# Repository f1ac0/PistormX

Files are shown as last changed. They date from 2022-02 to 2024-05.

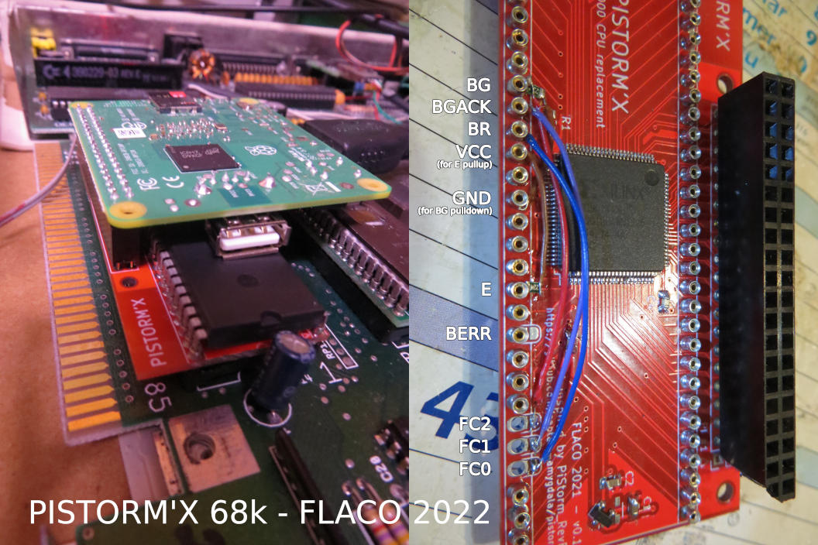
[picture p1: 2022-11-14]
Alpha/PiStormX-68k/PistormX68k.jpg

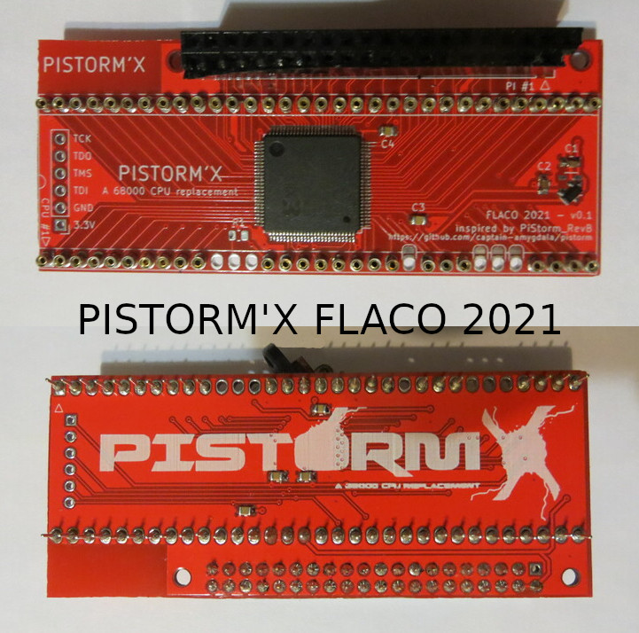
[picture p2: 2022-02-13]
Alpha/PistormX FLACO 2021.JPG

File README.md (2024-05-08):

# Pistorm'X
If you don't know about Pistorm, the MC68000 CPU replacement using a raspberry Pi, see here : https://github.com/captain-amygdala/pistorm

This PiStorm'X is a simplified CPU board, where all the logic is integrated inside a single CPLD with 5V compatible IOs.

The "Alpha" directory contains the PCB design and CPLD logic files for the first design of the Amiga 500 board and possible mods.

The "Beta" directory shares a second generation of boards for the Amiga 500, Amiga 600 and Amiga 1200. To enjoy both the speed of the PiStorm and the compatibility of the original hardware, they include the ability to disable the Pi and run the original 68k CPU, and the A500 and A600 ones also add 2MB of autoconfig Fast RAM.

Please read the README files there for more info.

# Experimental status
These boards are still experimental, not well tested, and might not work with all system revisions and Pi or 68k software nor provide the same performance or feature than the original. That it works for me does not mean that it will work for you. For this reason you are welcome to assemble your own and share test reports in the discord channel named "beta-testing-pistormx". And for this same reason this board or derivatives must not be sold to end users : do not sell it and do not buy it yet.

- I am an end user, where can I buy it? Buy one of the original PiStorm CPU boards.
- I am a builder, can I sell it? For now, please test it and report your test results.
- I am a maker, can I build derivatives? For now, please test it and report your test results.

# Acknowledgements
The board and its firmware are inspired by the original Pistorm : https://github.com/captain-amygdala/pistorm.
I would like to thank Claude Schwarz for designing and open sourcing the Pistorm and for letting other projects like this one use the name and get inspired by the source code.
Thank you also to EDU_ARANA for letting me use his Pistorm logo with some modifications on the PCB silkscreen.
It is not supported by the PiStorm developers, please don't bother them with issues you might have with it.

# Disclaimer
This is a hobbyist project, it comes with no warranty and no support. Also remember that the Amiga machines are about 30 years old and may fail because of such hardware expansions. Use with caution it could burn your Pi, your Amiga, your house.

I publish my work under the CC-BY-NC-SA license. You may build a board for you or your friend but will not sell or buy it commercially because it is experimental. You must keep the original author's name, source repository (https://github.com/f1ac0/PistormX) and licensing conditions even if you modify the product.

If you find it useful and want to reward my hard work : I am always looking for Amiga/Amstrad CPC and such retro hardware to repair and hack, or software licenses for these. Other than that, give to charities and reduce your carbon footprint.

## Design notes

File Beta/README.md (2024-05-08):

# PiStorm'X Work in progress

NOT ALL DESIGNS IN THIS DIRECTORY ARE TESTED.

If you don't know about PiStorm, the MC68000 CPU replacement using a raspberry Pi, see here : https://github.com/captain-amygdala/pistorm. This PiStorm'X is a simplified CPU board, where all the logic is integrated inside a single CPLD.

# Experimental status
These boards are either experimental, not finished, not yet tested, and might not work for you, have bugs with some system revisions and Pi or 68k software, or have less performance or feature than the original. For this reason you will find here source files only, not fabrication files or ready to use binaries. If you have enough development skills to use them and know what you are doing, you may assemble your own and share test reports in the discord channel named "beta-testing-pistormx". And for this same reason these boards or derivatives must not be sold to end users.

I publish my work under the CC-BY-NC-SA license. You may build a board for you but will not sell or buy it commercially because it is experimental. You must keep the original author's name, source repository (https://github.com/f1ac0/PistormX) and licensing conditions even if you modify the product.

If you find it useful and want to reward my hard work : I am always looking for Amiga/Amstrad CPC/C64 and such retro hardware to repair and hack, or software licenses for these. Other than that, please give to charities and reduce your carbon footprint.

# Acknowledgements
The board and its firmware are inspired by the original PiStorm : https://github.com/captain-amygdala/pistorm.
I would like to thank Claude Schwarz for designing and open sourcing the PiStorm and for letting other projects like this one use the name and get inspired by the source code.
Thank you also to EDU_ARANA for letting me use his PiStorm logo with some modifications on the PCB silkscreen.
It is not supported by the PiStorm developers, please don't bother them with issues you might have with it.

# PiStorm'X 500
The original PiStorm'X project for the Amiga 500 was shared in February 2022. In November 2022, I published the PiStorm'X-68k, a modification to the original project that allow keeping and using the original 68000 by deactivating the PiStorm when needed using a long reset.

This PiStorm'X 500 is an updated board for the Amiga 500 :
- including the PiStorm'X-68k modifications,
- moving the Pi away from the 68000, over the A500 ROM, in order to improve thermal repartition,
- adding 2MB of Fast RAM, which is useful especially during 68000 operation when the Pi is disabled : there was enough room on the two sided board and I believe it is a nice addition to the stock Amiga 500.

/!\ This 1.0 revision board need a patch wire between pin 15 of the 68k header to the pad marked OVR /!\ Do not connect anything else to this pad and check that the BGACK solder jumper is not shorted to the BGACK pin. /!\

The development of this board has been painful. I killed the 7805 Super Fat Agnus of my Rev8a in the development process, because of a dodgy home designed and printed ZIF64 socket that doesn't lock correctly, and an idiot operator that touched the pins without ESD protection. I am looking for an affordable replacement. Then I fought a timing problem caused by the slow transition on the 7MHz clock, because I thought it was a good idea to route it to a global clock pin of the CPLD. It was not - see https://support.xilinx.com/s/article/3226, on the Rev6 with Agnus 8372 318069-02 they are about 25ns, compared to 10ns on my A600 Rev1.5 with Agnus 8375 318069-10 - and this is the reason for the patch wire.

This board is actually working on my A500 Rev6.

# PiStorm'X 600
The PiStorm'X 600 brings the same features as the PiStorm'X 500 to the Amiga 600 : maintain reset during 6 seconds or more to use the 68000, and benefit of 2MB of Fast RAM.

This board is actually working on my A600.

# PiStorm'X 1K2
I have heard about the PiStorm32 for the Amiga 1200 and I wanted to make my own in the Pistorm'X way.

This is not yet finished and untested.

- There are two board layouts : the first board steals the component placement form the PiStorm32-lite ; the second "alt" one offers a more "traditional" design to access the Pi in the trapdoor. Both boards share the same logic but have different CPLD pinout and so will require different bitstreams. With the latter if you don't mind leaving the trapdoor open you may install a standard pin header for the Pi GPIO, leaving the A1200 edge connector as the only special part.
- Since it needs to cope with 32 bits operation with misaligned addresses and dynamic bus sizing, it requires a larger XC95288 CPLD, both in pin count and macrocells.
- This added logic must still be full of bugs and may never work.
- I reused the Pi pinouts from the Pistorm32-lite and since it does not have room for the jtag anymore, the device needs to be programmed externally.
- Even with the same Pi pinouts, it will need updated emulators that does not try to program a FPGA at power up : I hope this will be possible to deactivate it in future upstream releases.
- Like the original PiStorm'X that is not limited by external buffers, it might also be possible to use a faster protocol to speed up chip access a little bit. Or offload some complexity to the emulator to fit inside an even smaller/cheaper CPLD.

For sure this will need some more effort to first make it work !

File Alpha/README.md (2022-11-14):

# Pistorm'X
If you don't know about Pistorm, the MC68000 CPU replacement using a raspberry Pi, see here : https://github.com/captain-amygdala/pistorm

This Pistorm'X is a simplified CPU board, where all the logic is integrated inside a single XC94144XL-10TQ100 CPLD with 5V compatible IOs.

It has major differences in the logic implementation to accommodate the slower CPLD and may behave differently than the original Pistorm CPU board. A challenge has been to get rid of the 200MHz clock since the fastest Xilinx part in this series, the 5ns one, is rated for 178MHz max and is overpriced because of the chip shortage. Not using the PI_CLK makes the firmware really different from the original : a standard 10ns XC95144 can now deal with both the M68000 bus cycle synchronously to the 7MHz clock, and the asynchronous communication with the Pi that is just within the 10ns limit. 

The Pistorm'X logic is also provided for the original Pistorm CPU board. See the CPLD/Pistorm subdirectory to try it on your board.

Why you may consider building a Pistorm'X :
- This is even cheaper than the original board thanks to its single chip and 2-layer PCB.
- It is easier to assemble manually : there is only one QFP package, the board is less crowded, with 0805 caps, and the friendly 2-layer PCB with thermal relief makes it less vulnerable to cold joints.
- Maybe this will prove to be a suitable CPU board replacement. Your test contribution can help that.
- It runs with the same Pi software. Except CPLD programming : do not burn Altera bitstream on Xilinx device or vice versa !
- Because everything is reprogrammable in the CPLD, it may do things not possible on the original hardware :
  - Buffering write operations,
  - Installing it at the same time as the 68000 CPU : check the PistormX-68k folder for more info.

Why you should prefer the original CPU board :
- This Pistorm'X is alpha status. So far it is not guaranteed that it will work in your system or support all the features of the original.
- It is not an official board.
- It will probably not be compatible with future improvements or there will be delays to implement them.
- The actual CPLD pinout was chosen only to ease PCB routing and use a cheap 2-layers PCB. Future versions for different targets (A600, A2000...) will probably do the same and require a different CPLD pinout for each board, which means dedicated firmware files.
- The v0.1 board was routed with the actual Pistorm firmware in mind, so actually the 7MHz clock does not take advantage of a Global Clock pin of the CPLD : pinout may also change in next releases of this board.

# Experimental status
This board is experimental, not yet well tested, and might not work with all system revisions and Pi or 68k software or provide the same performance or feature than the original. That it works for me does not mean that it will work for you. For this reason you are welcome to assemble your own and share test reports in the discord channel named "beta-testing-pistormx". And for this same reason this board or derivatives must not be sold to end users : do not sell it and do not buy it yet.

- I am an end user, where can I buy it? Buy an original Pistorm CPU board.
- I am a builder, can I sell it? For now, please test it and report your test results.
- I am a maker, can I build derivatives? For now, please test it and report your test results.

Available firmwares:
- 8 states cycle : follow the complete 8 states 68k bus cycle described in MC68000 user manual.
- 6 states cycle : use a 6 states bus cycle by skipping s5 and s6 states. Similar to the original Pistorm firmware that skip s7 and s0 to increase chip access speed according to SysInfo.
- 6 states cycle write buffer : use CPLD registers as double buffer to releases the Pi bus earlier during write operations ; SysInfo show a tiny increase in CPU performance but not in chip ram access speed.
- 4 states cycle : use a 6 states bus cycle by skipping s0, s1, s5 and s6 states.
- 4 states cycle write buffer : use a 4 states bus cycle and a write buffer ; no real speed increase according to SysInfo, maybe useful in other apps.

Tested so far :
- inside my own Amiga 500 rev8a,
- buptest,
- Musashi based emulator with basic configuration and KS1.3, 3.1 and DiagROM, few demos and games from floppy,
- EMU68 with HDD install of KS3.1, RTG and WHDLoad games, demos.

Os runs stable for hours installing files from floppies or from SDbox. All the many glitches and errors that I found in games and demos (music not in sync, freeze) so far are similar when using the Pistorm'X or the Pistorm.

# Acknowledgements
The board and its firmware are inspired by the original Pistorm : https://github.com/captain-amygdala/pistorm.
I would like to thank Claude Schwarz for designing and open sourcing the Pistorm and for letting other projects like this one use the name and get inspired by the source code.
Thank you also to EDU_ARANA for letting me use his Pistorm logo with some modifications on the PCB silkscreen.
It is not supported by the Pistorm developers, please don't bother them with issues you might have with it.

# Disclaimer
This is a hobbyist project, it comes with no warranty and no support. Also remember that the Amiga machines are about 30 years old and may fail because of such hardware expansions. Use with caution it could burn your Pi, your Amiga, your house.

I publish my work under the CC-BY-NC-SA license. You may build a board for you or your friend but will not sell or buy it commercially because it is experimental. You must keep the original author's name, source repository (https://github.com/f1ac0/PistormX) and licensing conditions even if you modify the product.

If you find it useful and want to reward my hard work : I am always looking for Amiga/Amstrad CPC and such retro hardware to repair and hack, or software licenses for these. Other than that, give to charities and reduce your carbon footprint. 

# BOM
- 1x XC95144XL-10TQ100 CPLD
- 1x 3.3v LDO, either SPX3819M5-L-3-3 or XC6206P332MR or equivalent
- 2x 1uF (or more) 0805 capacitors in C1 and C2
- 6x 100nF 0805 capacitors
- (1x 10k 0805 resistor in R1, not required in my case)
- 64x rounded socket pins. I use pins taken from a socket header. You can omit pins 11,12,13,22,26,27 and 28.
- 1x 2x20 2.54mm female pin header.

# Making it
Components are SMD, and have thin pin pitch. You need to know what you are doing.

Check for shorts at least between 5V, 3.3V, and GND traces before applying power !

CPLD code is generated and built using Xilinx ISE 14.7 IDE. Use the following process properties : opt_mode=Speed; opt_level=High; optimize=Speed; slew=Slow; terminate=Keeper.

The "JTAG" programming port does not need to be soldered since the CPLD can be programmed from the Pi itself, or if you use a separate programmer you can just maintain the connector in place during the few seconds required for programming.

To program it outside of the Amiga using the JTAG port, I use xsvfduino : https://github.com/wschutzer/xsvfduino. When it is already plugged to the motherboard, you must disconnect the 3.3v wire and turn on your system to power the board, otherwise your programmer will try to power the whole system, it will not work, and it might burn.

# Installation on the motherboard
Do NOT install the original CPU on top of the board inside the socket pins : leave it empty. I decided to use these because I previously used them for my IDE-RAM-A500 expansion, they fit well, and are cheaper, shorter and probably stronger than male rounded pins.

Some features use the Pi GPIOs that are connected to the JTAG programming port. You can connect your wires there if you want. For example EMU68 logging should be on TCK (untested).

# Programming the CPLD from the Pi
Instead of using the JTAG port you can program the CPLD from the Pi when it is already installed and powered by the Amiga motherboard.

Long story : see https://linuxjedi.co.uk/2021/11/25/revisiting-xilinx-jtag-programming-from-a-raspberry-pi/amp/. Thank you LinuxJedi for this HowTo.

```
sudo apt install build-essential libusb-dev libftdi-dev libgpiod-dev git cmake
git clone https://github.com/matrix-io/xc3sprog
```
Before building, edit xc3sprog/sysfscreator.cpp and change :
```
IOSysFsGPIO(24, 26, 27, 25)
```
Build:
```
mkdir xc3sprog/build
cd xc3sprog/build
cmake .. -DUSE_WIRINGPI=OFF
make
```
Flash:
```
sudo xc3sprog -c sysfsgpio_creator -v -p 0 pistormx.jed
```

# Using it
See the official Pistorm documentation.

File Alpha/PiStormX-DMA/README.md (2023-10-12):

# Pistorm'X with bus arbitration for DMA enabled peripherals
While discussing with a fellow PiStorm user on the AmigaFrance Forum, I discovered that peripherals that use Direct Memory Access (DMA) on the Amiga 2000 do not work with the actual PiStorm CPU boards. Having never used a "big box" Amiga myself I did not know about this fact.

Looking at the schematic of the A2000, I believe the CPU board need to support bus arbitration signals (BR, BG, BGACK) in order to float the address and data buses when other devices need them. On the PiStorm'X-68K logic, I used these signals, but as a bus master device in a reverse way to shut the real 68000 when the PiStorm emulator is active. However this means that the signals are available to the CPLD and the logic can be changed to behave like a CPU supporting DMA requests.

The files in this directory are an attempt to add the support of bus arbitration signals to the first PiStorm'X CPU board (not the ones in the Beta directory).
- They are not tested since I don't own an Amiga 2000. If you want to test it yourself on your system, feel free. If you have a spare/unused/broken one and want to make a donation to help the project, I'd be very happy.
- BR, BG, BGACK need to be connected as explained below on the first PiStorm'X board : if not, BR will be floating which will produce unexpected results
- The real 68000 need to be removed from the system/NOT installed on the PiStorm'X. Since the bus arbitrations are used in a normal "CPU way" this leaves now way to shut it down like the PiStorm'X 68K does. Il you install both the real 68K an the PiStorm they will use the bus at the same time, this will not work, and will probably break them.

When this is proven to work, I believe it will be great to build an A2000 CPU board with support to both the DMA devices and the real 68000.

# Experimental status
Pistorm'X is experimental, not yet well tested, and might not work with all system revisions and Pi or 68k software or provide the same performance or feature than the original. That it works for me does not mean that it will work for you. For this reason you are welcome to assemble your own and share test reports in the Discord channel named "beta-testing-pistormx".

Pistorm'X-DMA is even more experimental and untested.

# Making it
The first Pistorm'X board require a few modifications and a new firmware
- Connect the pin in _BG = CPU pin 11 to the solder jumper pad next to FC2 = CPU pin 26
- Connect the pin in _BGACK = CPU pin 12 to the solder jumper pad next to FC1 = CPU pin 27
- Connect the pin in _BR = CPU pin 13 to the solder jumper pad next to FC0 = CPU pin 28
- Pins in FC0 = CPU pin 28, FC1 = CPU pin 27 and FC2 = CPU pin 26 are still not required. If you install them you need to be careful NOT to connect them to the nearby jumper pad.

A board already modded for the PiStorm'X-68K will not need any modification.

Build the firmware using the same settings as the Pistorm'X and flash it on the CPLD using xsvfduino, xc3sprog or your preferred method.

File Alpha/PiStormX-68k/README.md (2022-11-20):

# Pistorm'X together with a 68000 chip ?!
Installing a fast Amiga accelerator breaks compatibility with original games and demos. Users of these devices such as the Pistorm are forced to rely on WHDload, or to have another Amiga on their desk to have access to these many legacy softwares.

The Pistorm'X-68k is now the solution to boot either the Pistorm or the original 68000 CPU inside one single machine.

Power on and boot using the Pistorm. Maintain a long reset and the Amiga will now boot using the 68k.

The Pistorm'X was created in 2021 as a replacement CPU board for the Pistorm, using less components, a cheaper PCB, easier to assemble, and freeing a GPIO pin on the Pi. Since they were more robust and lower profile, I used the same female pins as my A500-IDE-RAM board to attach the board to the host motherboard. I also broke out a few unused signals on solder jumpers. Along with a new firmware, these make it possible to modify existing Pistorm'X boards to host the DIP 68000/68010 !

To make room for the huge clock counter required to time the long reset, the double write buffering has been removed from this firmware : it is similar to the "4 states cycle" version of the PistormX firmwares.

# Experimental status
Pistorm'X is experimental, not yet well tested, and might not work with all system revisions and Pi or 68k software or provide the same performance or feature than the original. That it works for me does not mean that it will work for you. For this reason you are welcome to assemble your own and share test reports in the Discord channel named "beta-testing-pistormx".

Pistorm'X-68k is even more experimental.

# Making it
The Pistorm'X board require a few modifications and a new firmware ! Do not plug a 68k unless these mods have been completed !
- Install the Pi socket as high as possible : it is possible to gain 1 to 2 millimetres this way, otherwise the USB port touching the top of the 68000 will prevent to seat the Pi correctly and may lead to bad contacts problems.
- Install a pulldown on _BG = CPU pin 11 through a ~20K resistor to GND = CPU pin 16 or 53
- Install a pullup on E = CPU pin 20 through a 100~200K resistor to VCC = CPU pin 14
- Connect the pin in _BG = CPU pin 11 to the solder jumper pad next to FC2 = CPU pin 26
- Connect the pin in _BGACK = CPU pin 12 to the solder jumper pad next to FC1 = CPU pin 27
- Connect the pin in _BR = CPU pin 13 to the solder jumper pad next to FC0 = CPU pin 28
- Install a pin in the BERR hole = CPU pin 22 : it is not used by the Pistorm however the 68k require the pullup provided by the motherboard.
- Pins in FC0 = CPU pin 28, FC1 = CPU pin 27 and FC2 = CPU pin 26 are still not required. If you install them you need to be careful NOT to connect them to the nearby jumper pad.

Build the firmware using the same settings as the Pistorm'X and flash it on the CPLD using xsvfduino, xc3sprog or your preferred method. However I recommend to install a 68K only after it has been updated and modified successfully.

# Using it
You should consider active cooling when using the original board with the Pi placed just over the 68000, especially if you use the system for long periods. New boards layouts may solve this by placing the Pi over the A500 ROM (and with the ARM CPU on the top ?).

When no Pistorm emulator is active, the system boots using the 68000.

As soon as the Pistorm emulator starts, the system will reboot using the Pistorm. Maintain the reset during at least 6 seconds to disale Pistorm and use the 68000. Maintain a long reset again to go back to the Pistorm.

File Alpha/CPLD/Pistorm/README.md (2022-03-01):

# Pistorm'X firmwares for the original Pistorm CPU board
If you don't know about Pistorm, the MC68000 CPU replacement using a raspberry Pi, see here : https://github.com/captain-amygdala/pistorm

The Pistorm'X is a simplified CPU board, where all the logic is integrated inside a single XC94144XL-10TQ100 CPLD with 5V compatible IOs. See here : https://github.com/f1ac0/PistormX

It has major differences in the logic implementation to accommodate a slower CPLD, especially getting rid of the 200MHz clock, freeing one GPIO for future use.

Here you can find adapted Pistorm'X firmwares to be used on the original Pistorm CPU board with external buffer chips :
- basic : mostly similar to the features of original Pistorm firmware.
- skip s5s6 : skip s5 and s6 states when not in peripheral bus cycle.

Provided .svf files are built for the EPM240 CPLD.
Do not burn Altera bitstream on Xilinx device or vice versa ! Use with caution it could burn your Pi, your Amiga, your house.

# Experimental status
Actually even if they succeed the buptest and boot both Musashi and EMU68, they are unstable on my board. For example in amigaTestKit, testing the RTC clock does crash : maybe it has something to do with peripheral cycles.

Pistorm'X is experimental, not yet well tested, and might not work with all system revisions and Pi or 68k software or provide the same performance or feature than the original. That it works for me does not mean that it will work for you. For this reason you are welcome to assemble your own and share test reports in the Discord channel named "beta-testing-pistormx".

# Making it
Clone the Pistorm repo and replace the verilog file in the rtl subdirectory.

Build from the command line, replacing the path and version of your Quartus installation :
```
~/Quartus/17.0/quartus/bin/quartus_sh --flow compile pistorm
~/Quartus/17.0/quartus/bin/quartus_cpf -c -q 100KHz -g 3.3 -n p output_files/pistorm.pof pistorm.svf
```
If you choose to build it from the interface, make sure to set the correct 100KHz frequency in the programmer/svf options.

# Programming the CPLD from the Pi
Replace EPM240_bitstream.svf with the new .svf file, then run flash.sh as you usually do.

# Using it
See the official Pistorm documentation.

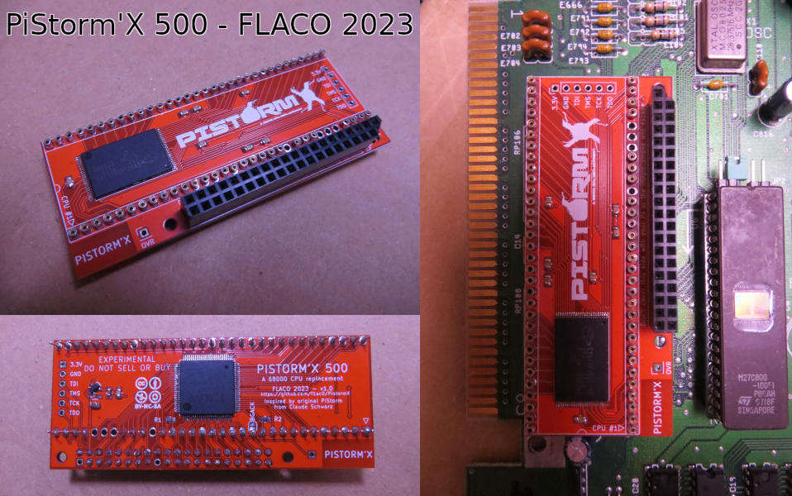
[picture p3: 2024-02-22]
Beta/PistormX 500 DIP/PiStormX500.jpg

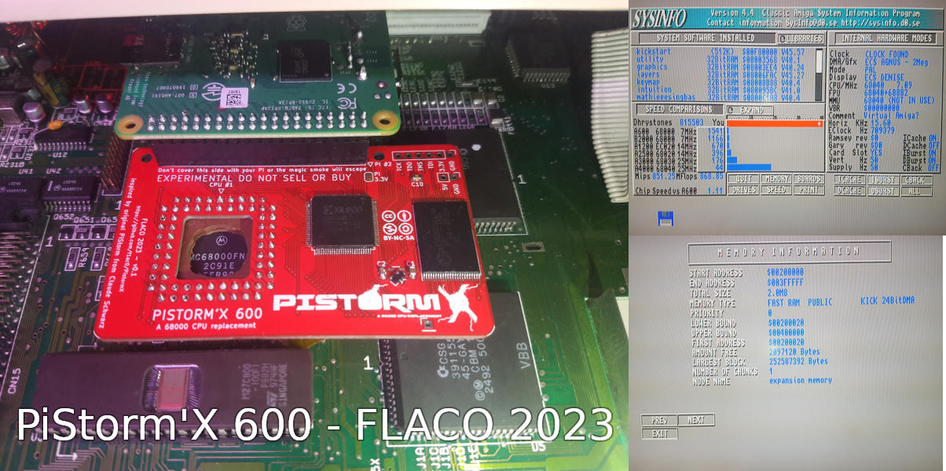
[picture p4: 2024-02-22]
Beta/PistormX 600/PiStormX600.jpg

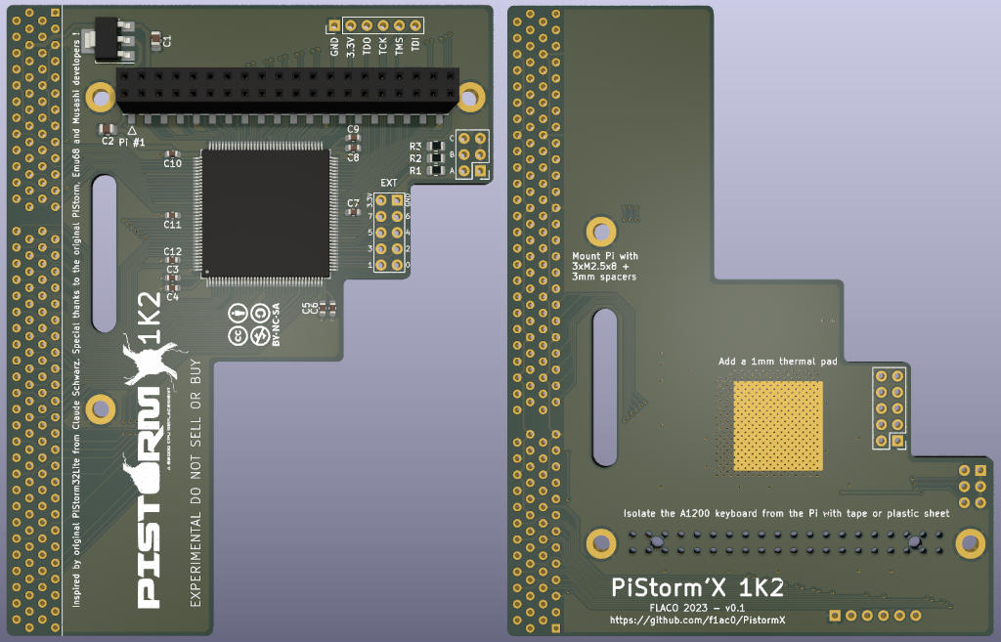
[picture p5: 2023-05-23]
Beta/PistormX 1K2/PiStormX1K2.jpg

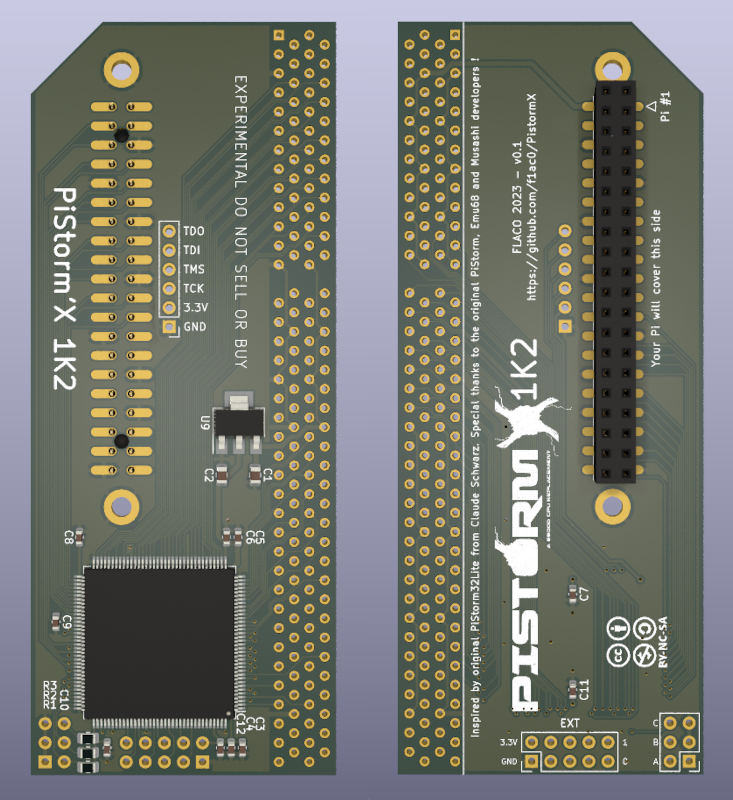
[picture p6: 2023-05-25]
Beta/PistormX 1K2 alt/PiStormX1K2 alt.jpg

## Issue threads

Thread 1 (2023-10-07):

PistormxDMA Amiga 2000 eatx troubles.

Trakman500, 2023-10-07:
Hello! I’ll describe it in order: pistormx of the first revisions (without expansion cards in Zorro) - problems with the mouse cursor which trembles convulsively on the screen and is practically uncontrollable. Changing the firmware and modifying the pistormx itself to support dma solves the problem with the mouse. everything works well. When you insert a sound card into a Zorro slot (any), instead of sound from the card, a high-frequency loud noise is emitted and music plays very quietly... prlcheck (prelude utility) displays an error that changes when the utility itself is launched again.
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

f1ac0, 2023-10-08:
Hi.
I am happy to have feedback from a PiStormX user.
Thank you for sharing your experience with the A2000, which seems to prove that the PiStormX-DMA logic is working. On my side, I couldn't find an A2000 at a decent price to test it, and to create a CPU board supporting both the 68k and the bus arbitration/DMA at the same time.

About the Prelude, and PrlCheck : according to your screenshot, it does something with address 0xE90000 which is "Secondary  [auto-config space]  (usually 64K I/O boards)" according to the Amiga memory map. I believe you are using Emu68 ; according to the last source files it does not seem to have a special behavior when accessing this address range (https://github.com/michalsc/Emu68/blob/0eaf3ab2c0641bb168b6b0c8c862182f3b8353cf/src/aarch64/vectors.c#L401) and I believe it also does not use cache (https://github.com/michalsc/Emu68/blob/0eaf3ab2c0641bb168b6b0c8c862182f3b8353cf/src/cache.c#L212). If you are using this same version, I do not see an obvious problem here.

On the hardware side, looking at the A2000 schematic, I believe that it is not a problem with logic voltage levels since address and data buses are buffered by U600-U604. Otherwise some CMOS chip on the expansion board might have not registered correctly the 3.3V outputs form the CPLD on the PiStorm'X board. (or it uses E, VPA and VMA that are not buffered).

The last thing I can think of is timing problem, especially if the offset of the error changes when you run  prlcheck several times. For this it could be useful to confirm the address it uses and probe the bus to see what is happening.

Trakman500, 2023-10-09:
After much torment with the a2k and the card, I decided to plug everything back into the a500... I connected the pi storm there and heard the same grinding and whistling noise as on the a2000! Well, I immediately thought maybe something had happened to my card... I returned the firmware and turned everything on again on the a500, the sound became normal... I put the pi storm with sound back in a2k, there is no sound at all, the card is checked with the same errors... I flashed back the pi storm with DMA support... the same thing, but there was a grinding and whistling noise... checking the prelude with the utility again produced chaotic errors and the guru machine when accessing the card... recorded some guru errors - 8000 0004 - 08184800, 08183260, 081е43f0, 08003020 etc
 The utility's check of the card sometimes goes through completely, but the test sound it makes is still the same bad noise...

f1ac0, 2023-10-09:
I recommend installing only boards+firmware that are aware of bus arbitration/DMA/bus master inside systems or with expansion boards that use it. Otherwise both the CPU board and expansion boards will talk at the same time on the buses, making unpredictable behavior, and maybe breaking something.

On the A500 where BR and BGACK are pulled up and not connected anywhere else, the PiStormXDMA logic will behave the same as the "pistormx - 4 states cycle write buffer" one. If this is the one you "returned to", I honestly don't understand what happened on the A500 at least. Do you unplug the board each time you flash it, and maybe there could be a bad contact somewhere/sometimes (even though all signals on the 68k socket are digital and a bad contact will prevent it to work at all - but maybe on the interrupt lines, audio channels from paula being interrupt 4 ?)

Before your last message, I was wondering if the JIT settings in emucontrol could change something with the prelude card like it does for some games?

Trakman500, 2023-10-10:
Today I’ll try to play around with the emu68 control in symbiosis with the Prelude checking utility.

Trakman500, 2023-10-11:
hi! In principle, I did not achieve any big changes. pistorm equipped with jumpers so that they can be removed or installed at any time.
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
I noticed that with them (jumpers) and without them on the a2000 everything is determined and works the same... I achieved the following results with it, but they are also not constant...
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

Trakman500, 2023-10-12:
I found on one of the forums that the prelude works on a2k with the original pi storm -

Ich hab ja mit Spannung auf den Treiber gewartet. Denn die Prelude (bzw. das Replikat) war in meinem A2000 mit Emu68 / Pistorm und dem Emu68 RTG Treiber mit den alten Treibern als Soundkarte per AHI oder Prelude direkt kaum sinnvoll nutzbar. Es kam ständig zu Abbrüchen.

Und in der Tat funktioniert genau das jetzt erfreulich gut. Wo es vorher zu Abbrüchen kam, stottert es jetzt leicht und insgesamt ist das Playback insgesamt viel stabiler. Gestern abend hat das System mit AmigaAMP 3.33 und MP3 Playback via AHI fast drei Stunden lang problemlos durchgehalten. Auch Hippoplayer dudelt jetzt schon eine Weile problemlos vor sich her.

Einzig Play16 per direktem Prelude Output spielt erst problemlos und hängt dann nach ein, zwei Minuten einfach ohne Möglichkeit zum Abbruch. Beim Playblack via AHI passiert das nicht. Wobei das natürlich auch Zufall sein kann, mein Setup ist ja in dieser Form eher experimentell.

A2000 Rev.6, Pistorm 2k / Emu68, AmigaOS 3.2.1, Freeway Pro, X-Surf 100, AT-Bus Clone, Prelude + MPEGit Replikat

https://www.a1k.org/forum/index.php?threads/85465/page-8

Why does pi storm x behave like this? Today I'll try all the firmwares.

Trakman500, 2023-10-12:
I tried it a little later... same result

Trakman500, 2023-10-12:
I conducted the same experiment again with the DMA firmware and the removed jumpers that I installed on the pistormx - on the a500... it loads normally, the prelude is detected perfectly, but when I launched the digibooster I noticed how slowly the windows were drawn on the screen... choosing the prelude as the sound device and After loading the module, I heard the same creaking and noise... I changed the firmware to 6 state, everything worked fine on the a500...

f1ac0, 2023-10-12:
>I found on one of the forums that the prelude works on a2k with the original pi storm
What I see in original PiStorm logic is that bus arbitration signals M68K_BR_n, M68K_BGACK_n are not connected anywhere and M68K_BR_n is tied up.
If the prelude works with that, then it does not use DMA.

I read here https://www.amigaimpact.org/forums/topic/tableau-perf-winuae/page/6/#post-375851 that it is recommended to use a "long hold" firmware to use the original PiStorm inside an A2000. I can see some binary files by this name here https://github.com/LemaruX/PiStorm-Firmware/tree/main however I cant find a source for it.

>with the DMA firmware and the removed jumpers
Without the jumper wires I can see on your photo, then the BR input of the DMA firmware is floating and receiving noise from ambient, so the CPLD logic might be requesting the bus and releasing it randomly.
This can explain your following sentence since according to pure randomness the bus throughput could be halved :
>when I launched the digibooster I noticed how slowly the windows were drawn on the screen

You should leave your jumper wires always connected. When using non-DMA logic unused pins are just connected to a weak pull (keeper) inside the CPLD.

> on the a500... it loads normally, the prelude is detected perfectly
your prelude is connected to the A500 ? Isn't it a board for A2000 ? https://amiga.resource.cx/exp/prelude

> I changed the firmware to 6 state, everything worked fine on the a500...
I can add the bus arbitration/dma logic to the "6 states cycle write buffer" however I'm quite lost in what works and what doesn't.

Trakman500, 2023-10-13:
I connect to the a500 using this adapter
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
[A-Zorro-Edge-2b.sch.pdf](https://github.com/f1ac0/PistormX/files/12889606/A-Zorro-Edge-2b.sch.pdf)

Trakman500, 2023-10-13:
Remade and reflashed to new firmware -
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

Trakman500, 2023-10-13:
The situation is the same... on the A500 the card plays okay and the utility test passes, but the mouse cursor twitches... at first I thought it was because of the RTG, but in the boot menu it also twitches... I removed the card and the cursor stopped twitching. I recorded a video of how it all works on the a500, but the volume doesn’t fit here... on the a2000 the situation with the card is the same... with the cursor everything is ok, the card is mistakenly checked by the utility and when playing only noise and I also noticed the music that plays in the background of noise You can hear that the samples are played at a faster speed! that is, the sampling frequency has been increased! how can this be...?

f1ac0, 2023-10-13:
I understand your setup a bit more.

A difference I can see between the A2000 and the A500 with this ZorroIIedge adapter is that the adapter does not have TTL logic ICs to buffer the address and data buses. However according to your Prelude schematic the signals are fed to 74F chips and to ATF20V8B chips that have TTL input levels, so the 3.3V from the CPLD might not be an issue there.

Also according to the Prelude schematic, BR, BG and BGACK are not connected. So it does not use DMA/bus master and the PiStorm'X-DMA logic with bus arbitration is useless here !

The dropmefiles link says the videos are being converted and the download button just refreshes the page when I click it.

I believe this leaves us with :
- on the hardware side, timings or interrupt problem : have you tried the 8 states cycle logic ? (I guess that you did according to a previous comment but it is best to confirm)
- something on the software side (68K application/driver, emu68 or its config)
-

Trakman500, 2023-10-14:
Cpld was checked several times... all contacts were soldered ok. I flashed the firmware with 8 states (I also flashed it before) well, the same thing... on the a500 everything is ok, on the a2k the cursor twitches and is practically uncontrollable... I noticed that the cursor comes back to normal when the firmware is uploaded with DMA support... then the cursor is not twitches and the mouse works well, this concerns a2k. I have two SD cards with EMU68, one with the Coffin system, the other 3.2.1 with RTG... both have the correct drivers installed for the prelude, everything has been tested several dozen times... on the a500... and even on the a2000 only with negative result so far... that is, I can’t even think about the software part that there’s something wrong there... today I run the diagrom on a2k, all tests passed without errors. :(
what could be the problem???

Trakman500, 2023-10-25:
Hi!
Сlaude Schulz pointed to the source with a long hold - https://github.com/captain-amygdala/pistorm/blob/c1e90713befeac724a83f36781bf2507d073b3ad/rtl/pistorm.v#L266

Trakman500, 2023-10-26:
I found the reason for the bad behavior of the mouse... it turned out to be a denise chip :(

Trakman500, 2023-11-13:
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
Hello! I found the reason... it was the wrong resistor assemblies (rn902, rn102) that I installed :( on the a2000 motherboard. At the moment, the pistormx has the pistormxdma firmware - 6 states cycle write buffer, everything works well. A little later I will test all the other firmwares .
I express my gratitude to everyone who took part in this! Thank you!
ps pistormx - still works on a2000 without long hold :)
pps to Flac0, if you need to test something, I’m always happy to help! Thanks again!

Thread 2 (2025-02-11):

PiStormX Beta A500 DIP - troubles in Amiga 2000 Rev. 6.2

tkurbad, 2025-02-11:
Hi,

yesterday, I finished building an example of the A500 DIP beta version of the PiStormX.

It works beautifully in my A500 Rev. 6A. Long reset deactivates the PiStorm and the system comes up with the 68k + 2 MB fastram. Very neat!

I was hoping for a similar behavior in my A2000. But with the PiStormX, the A2000 fails to start with a yellow screen, which I believe could indicate a bus error.

I fully populated the PiStormX, including both pull-ups and all pins. My suspicion is that I'd need to get rid of the pull-ups, but wanted to confirm first.

Thanks
Torsten

f1ac0, 2025-02-18:
Hi,

There are two different Pistorm'X versions using a DIP 68K socket, and since you are talking about the 2Mb fast ram you must be using the "Beta 500" one.

The 68K CPU is designed to use bus arbitration signals, and some system / expansion boards use them to do what they call "Bus mastering" : shut up the CPU, and drive the CPU bus to use RAM or the system chipset by themselves for a few cycles, then release the but. This is used by some Amiga 2000 expansion boards.
These signals are also used by CPU replacement boards, when they do not require you to remove the existing CPU, such as the PiStorm'X 500 : in fact they act as as bus mastering board and they use these signals to shut the CPU up and replace it permanently on the bus. The downside is that this leaves no way for other expansions to request the bus, this is why these CPU replacement boards are not able to support "Bus mastering" expansions. And also you cannot have two CPU replacement boards in your system at the same time !

Since your PiStorm'X 500 board is working inside your A500, the problem you are facing may be that there is another CPU replacement board inside your A2000, or an expansion that tries to use bus mastering at boot.

The alpha version of the PiStorm'X has a firmware that supports a bus arbitration logic similar to the original 68000 to support "Bus mastering" expansions. To use it, you need to remove the 68000 from your system : because of that the 2Mb of "slow" fast ram feature is pointless and I did not bother to code such a firmware for the "500" board. You may try it.
It could be possible to create a CPU board for the A2000 hosting both the 68K and the Pi and supporting bus mastering at the same time. However I do not own an A2000 and failed to buy one at a decent price.

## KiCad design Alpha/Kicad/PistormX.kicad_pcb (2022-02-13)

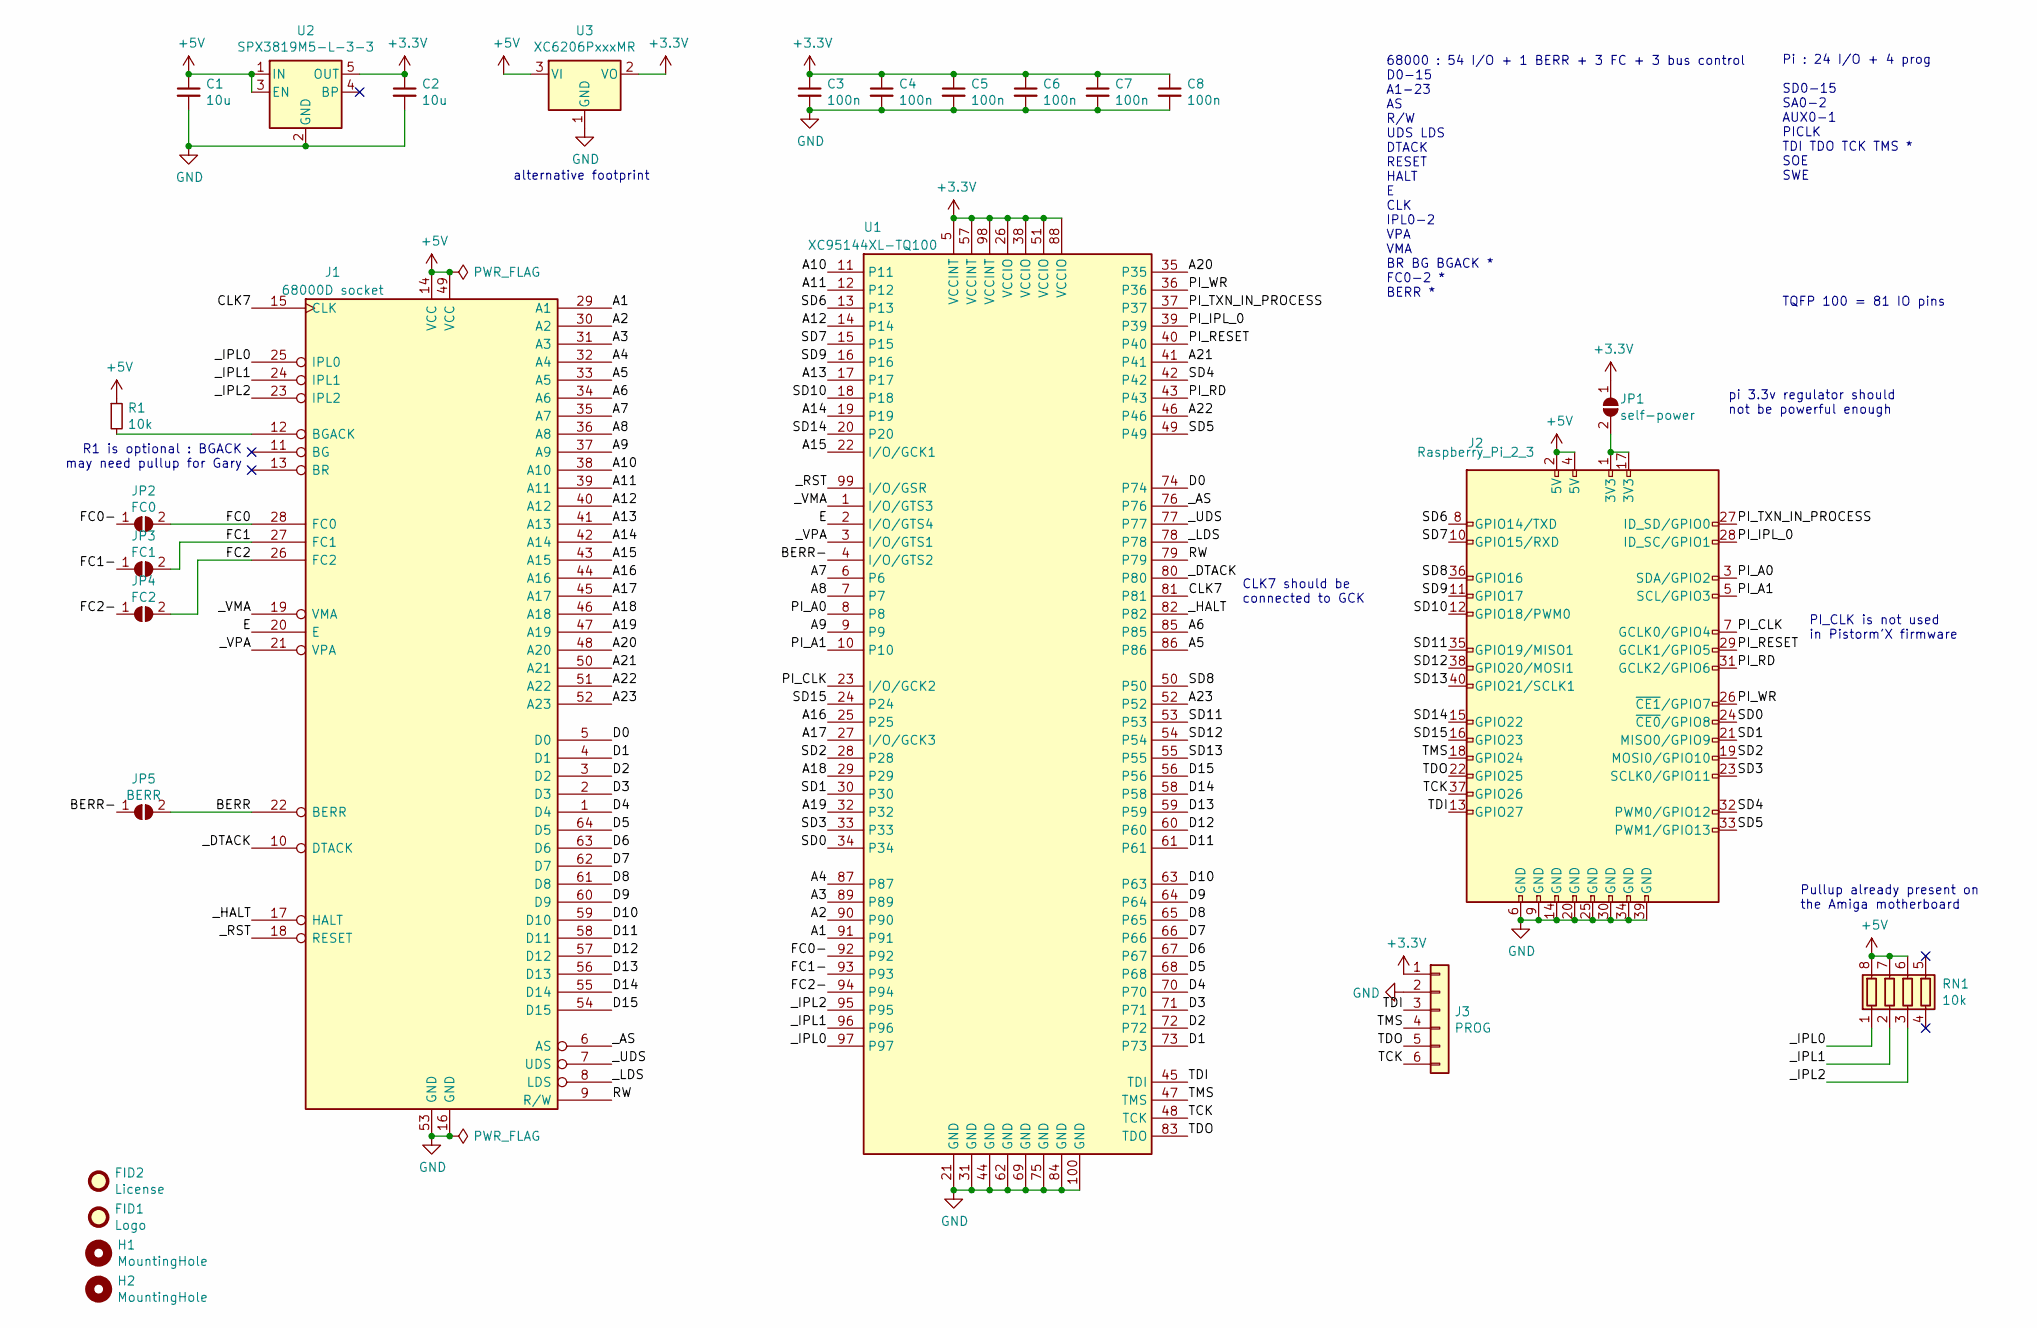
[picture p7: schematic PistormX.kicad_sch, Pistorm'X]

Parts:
C1, C2: 10u; C_0805_2012Metric
C3, C4, C5, C6, C7, C8: 100n; C_0805_2012Metric
FID1: Logo; PistormX
FID2: License; CC_BY_NC_SA_square_silkscreen
H1, H2: MountingHole; MountingHole_2.5mm
J1: 68000D socket; DIP-64_W22.86mm_BigPads1.4
J2: Raspberry_Pi_2_3; PinSocket_2x20_P2.54mm_Vertical
J3: PROG; PinHeader_1x06_P2.54mm_Vertical
JP1: self-power; SolderJumper-2_P1.3mm_Open_RoundedPad1.0x1.5mm
JP2: FC0; SolderJumper-2_P1.3mm_Open_RoundedPad1.0x1.5mm
JP3: FC1; SolderJumper-2_P1.3mm_Open_RoundedPad1.0x1.5mm
JP4: FC2; SolderJumper-2_P1.3mm_Open_RoundedPad1.0x1.5mm
JP5: BERR; SolderJumper-2_P1.3mm_Open_RoundedPad1.0x1.5mm
R1: 10k; R_0805_2012Metric
RN1: 10k; R_Array_Convex_4x0603
U1: XC95144XL-TQ100; TQFP-100_14x14mm_P0.5mm
U2: SPX3819M5-L-3-3; SOT-23-5
U3: XC6206PxxxMR; SOT-23

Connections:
+3V3: C2.1, C3.1, C4.1, C5.1, C6.1, C7.1, C8.1, J3.1, JP1.1 (A), U1.5 (VCCINT), U1.26 (VCCIO), U1.38 (VCCIO), U1.51 (VCCIO), U1.57 (VCCINT), U1.88 (VCCIO), U1.98 (VCCINT), U2.5 (OUT), U3.2 (VO)
+5V: C1.1, J1.14 (VCC), J1.49 (VCC), J2.2 (5V), J2.4 (5V), R1.1, RN1.6 (R3.2), RN1.7 (R2.2), RN1.8 (R1.2), U2.1 (IN), U2.3 (EN), U3.3 (VI)
/A1: J1.29 (A1), U1.91
/A2: J1.30 (A2), U1.90
/A3: J1.31 (A3), U1.89
/A4: J1.32 (A4), U1.87
/A5: J1.33 (A5), U1.86
/A6: J1.34 (A6), U1.85
/A7: J1.35 (A7), U1.6
/A8: J1.36 (A8), U1.7
/A9: J1.37 (A9), U1.9
/A10: J1.38 (A10), U1.11
/A11: J1.39 (A11), U1.12
/A12: J1.40 (A12), U1.14
/A13: J1.41 (A13), U1.17
/A14: J1.42 (A14), U1.19
/A15: J1.43 (A15), U1.22 (I/O/GCK1)
/A16: J1.44 (A16), U1.25
/A17: J1.45 (A17), U1.27 (I/O/GCK3)
/A18: J1.46 (A18), U1.29
/A19: J1.47 (A19), U1.32
/A20: J1.48 (A20), U1.35
/A21: J1.50 (A21), U1.41
/A22: J1.51 (A22), U1.46
/A23: J1.52 (A23), U1.52
/BERR: J1.22 (BERR), JP5.2 (B)
/BERR-: JP5.1 (A), U1.4 (I/O/GTS2)
/CLK7: J1.15 (CLK), U1.81
/D0: J1.5 (D0), U1.74
/D1: J1.4 (D1), U1.73
/D2: J1.3 (D2), U1.72
/D3: J1.2 (D3), U1.71
/D4: J1.1 (D4), U1.70
/D5: J1.64 (D5), U1.68
/D6: J1.63 (D6), U1.67
/D7: J1.62 (D7), U1.66
/D8: J1.61 (D8), U1.65
/D9: J1.60 (D9), U1.64
/D10: J1.59 (D10), U1.63
/D11: J1.58 (D11), U1.61
/D12: J1.57 (D12), U1.60
/D13: J1.56 (D13), U1.59
/D14: J1.55 (D14), U1.58
/D15: J1.54 (D15), U1.56
/E: J1.20 (E), U1.2 (I/O/GTS4)
/FC0: J1.28 (FC0), JP2.2 (B)
/FC0-: JP2.1 (A), U1.92
/FC1: J1.27 (FC1), JP3.2 (B)
/FC1-: JP3.1 (A), U1.93
/FC2: J1.26 (FC2), JP4.2 (B)
/FC2-: JP4.1 (A), U1.94
/PI_A0: J2.3 (SDA/GPIO2), U1.8
/PI_A1: J2.5 (SCL/GPIO3), U1.10
/PI_CLK: J2.7 (GCLK0/GPIO4), U1.23 (I/O/GCK2)
/PI_IPL_0: J2.28 (ID_SC/GPIO1), U1.39
/PI_RD: J2.31 (GCLK2/GPIO6), U1.43
/PI_RESET: J2.29 (GCLK1/GPIO5), U1.40
/PI_TXN_IN_PROCESS: J2.27 (ID_SD/GPIO0), U1.37
/PI_WR: J2.26 (~CE1/GPIO7), U1.36
/RW: J1.9 (R/W), U1.79
/SD0: J2.24 (~CE0/GPIO8), U1.34
/SD1: J2.21 (MISO0/GPIO9), U1.30
/SD2: J2.19 (MOSI0/GPIO10), U1.28
/SD3: J2.23 (SCLK0/GPIO11), U1.33
/SD4: J2.32 (PWM0/GPIO12), U1.42
/SD5: J2.33 (PWM1/GPIO13), U1.49
/SD6: J2.8 (GPIO14/TXD), U1.13
/SD7: J2.10 (GPIO15/RXD), U1.15
/SD8: J2.36 (GPIO16), U1.50
/SD9: J2.11 (GPIO17), U1.16
/SD10: J2.12 (GPIO18/PWM0), U1.18
/SD11: J2.35 (GPIO19/MISO1), U1.53
/SD12: J2.38 (GPIO20/MOSI1), U1.54
/SD13: J2.40 (GPIO21/SCLK1), U1.55
/SD14: J2.15 (GPIO22), U1.20
/SD15: J2.16 (GPIO23), U1.24
/TCK: J2.37 (GPIO26), J3.6, U1.48 (TCK)
/TDI: J2.13 (GPIO27), J3.3, U1.45 (TDI)
/TDO: J2.22 (GPIO25), J3.5, U1.83 (TDO)
/TMS: J2.18 (GPIO24), J3.4, U1.47 (TMS)
/_AS: J1.6 (AS), U1.76
/_DTACK: J1.10 (DTACK), U1.80
/_HALT: J1.17 (HALT), U1.82
/_IPL0: J1.25 (IPL0), RN1.1 (R1.1), U1.97
/_IPL1: J1.24 (IPL1), RN1.2 (R2.1), U1.96
/_IPL2: J1.23 (IPL2), RN1.3 (R3.1), U1.95
/_LDS: J1.8 (LDS), U1.78
/_RST: J1.18 (RESET), U1.99 (I/O/GSR)
/_UDS: J1.7 (UDS), U1.77
/_VMA: J1.19 (VMA), U1.1 (I/O/GTS3)
/_VPA: J1.21 (VPA), U1.3 (I/O/GTS1)
GND: C1.2, C2.2, C3.2, C4.2, C5.2, C6.2, C7.2, C8.2, J1.16 (GND), J1.53 (GND), J2.6 (GND), J2.9 (GND), J2.14 (GND), J2.20 (GND), J2.25 (GND), J2.30 (GND), J2.34 (GND), J2.39 (GND), J3.2, U1.21 (GND), U1.31 (GND), U1.44 (GND), U1.62 (GND), U1.69 (GND), U1.75 (GND), U1.84 (GND), U1.100 (GND), U2.2 (GND), U3.1 (GND)
unnamed: J1.12 (BGACK), R1.2
unnamed: J2.1 (3V3), J2.17 (3V3), JP1.2 (B)

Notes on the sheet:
CLK7 should be connected to GCK
Pi : 24 I/O + 4 prog SD0-15 SA0-2 AUX0-1 PICLK TDI TDO TCK TMS * SOE SWE
Pullup already present on the Amiga motherboard
alternative footprint
pi 3.3v regulator should not be powerful enough
R1 is optional : BGACK may need pullup for Gary
TQFP 100 = 81 IO pins
68000 : 54 I/O + 1 BERR + 3 FC + 3 bus control D0-15 A1-23 AS R/W UDS LDS DTACK RESET HALT E CLK IPL0-2 VPA VMA BR BG BGACK * FC0-2 * BERR *
PI_CLK is not used in Pistorm'X firmware

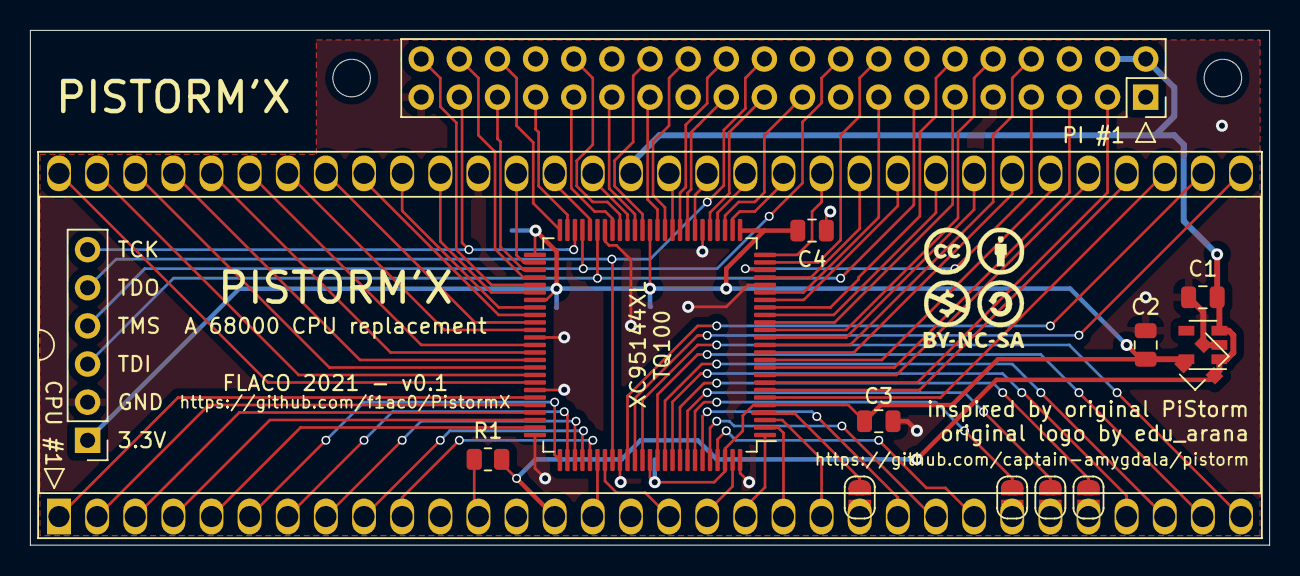
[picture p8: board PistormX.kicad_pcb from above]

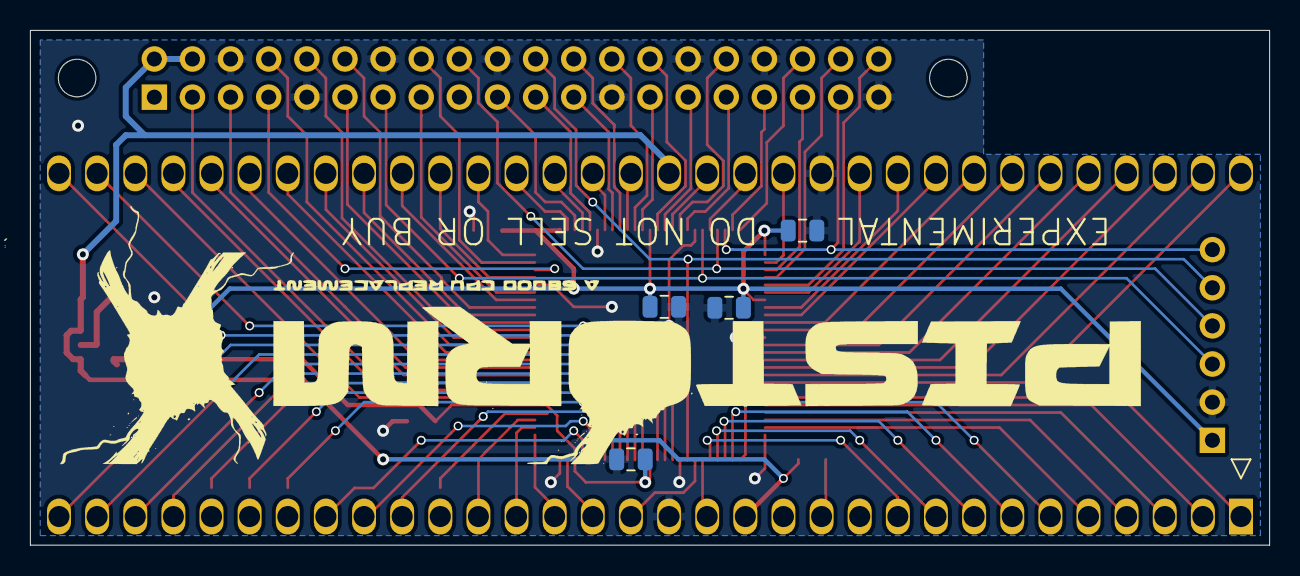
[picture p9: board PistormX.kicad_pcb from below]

Board: 2 copper layers, 82.6 x 34.3 mm, 23 parts (5 on the bottom side), 94 nets.

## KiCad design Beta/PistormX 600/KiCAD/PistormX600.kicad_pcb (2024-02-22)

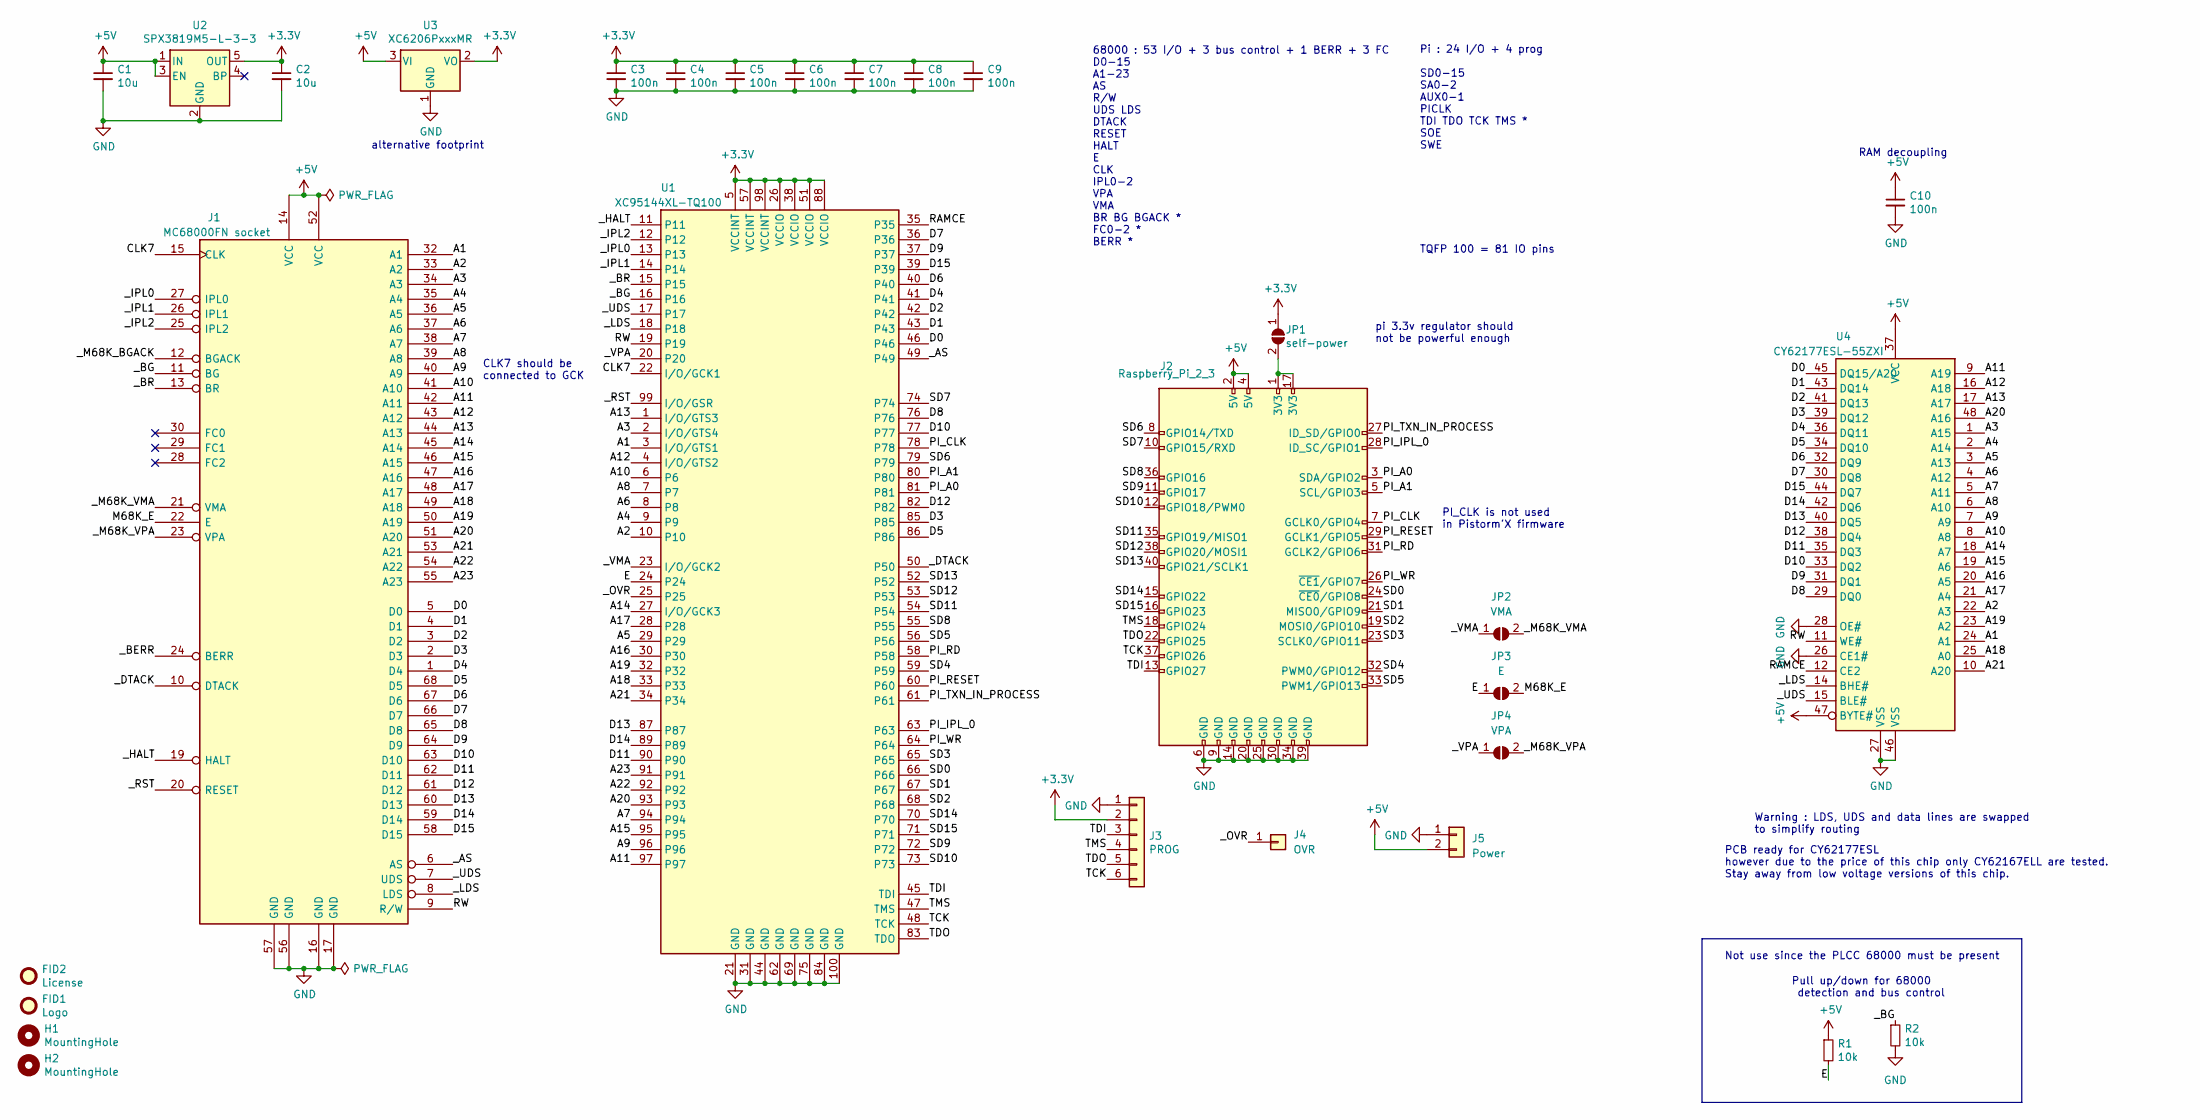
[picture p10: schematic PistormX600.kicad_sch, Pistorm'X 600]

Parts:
C1, C2: 10u; C_0805_2012Metric
C3, C4, C5, C6, C7, C8, C9, C10: 100n; C_0805_2012Metric
FID1: Logo; PIC_PistormX_43x10mm
FID2: License; CC_BY_NC_SA_square_silkscreen
H1, H2: MountingHole; MountingHole_2.5mm
J1: MC68000FN socket; PLCC-68_THT-SocketOnTop
J2: Raspberry_Pi_2_3; PinSocket_2x20_P2.54mm_Vertical
J3: PROG; PinHeader_1x06_P2.54mm_Vertical
J4: OVR; PinHeader_1x01_P2.54mm_Vertical
J5: Power; PinHeader_1x02_P2.54mm_Vertical
JP1: self-power; SolderJumper-2_P1.3mm_Open_RoundedPad1.0x1.5mm
JP2: VMA; SolderJumper-2_P1.3mm_Open_RoundedPad1.0x1.5mm
JP3: E; SolderJumper-2_P1.3mm_Open_RoundedPad1.0x1.5mm
JP4: VPA; SolderJumper-2_P1.3mm_Open_RoundedPad1.0x1.5mm
R1, R2: 10k; R_0805_2012Metric
U1: XC95144XL-TQ100; TQFP-100_14x14mm_P0.5mm
U2: SPX3819M5-L-3-3; SOT-23-5
U3: XC6206PxxxMR; SOT-23
U4: CY62177ESL-55ZXI; TSOP-I-48_18.4x12mm_P0.5mm

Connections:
+3.3V: C2.1, C3.1, C4.1, C5.1, C6.1, C7.1, C8.1, C9.1, J3.2, JP1.1 (A), U1.5 (VCCINT), U1.26 (VCCIO), U1.38 (VCCIO), U1.51 (VCCIO), U1.57 (VCCINT), U1.88 (VCCIO), U1.98 (VCCINT), U2.5 (OUT), U3.2 (VO)
+5V: C1.1, C10.1, J1.14 (VCC), J1.52 (VCC), J2.2 (5V), J2.4 (5V), J5.2, R1.1, U2.1 (IN), U2.3 (EN), U3.3 (VI), U4.37 (VCC), U4.47 (BYTE#)
/A1: J1.32 (A1), U1.3 (I/O/GTS1), U4.24 (A1)
/A2: J1.33 (A2), U1.10, U4.22 (A3)
/A3: J1.34 (A3), U1.2 (I/O/GTS4), U4.1 (A15)
/A4: J1.35 (A4), U1.9, U4.2 (A14)
/A5: J1.36 (A5), U1.29, U4.3 (A13)
/A6: J1.37 (A6), U1.8, U4.4 (A12)
/A7: J1.38 (A7), U1.94, U4.5 (A11)
/A8: J1.39 (A8), U1.7, U4.6 (A10)
/A9: J1.40 (A9), U1.96, U4.7 (A9)
/A10: J1.41 (A10), U1.6, U4.8 (A8)
/A11: J1.42 (A11), U1.97, U4.9 (A19)
/A12: J1.43 (A12), U1.4 (I/O/GTS2), U4.16 (A18)
/A13: J1.44 (A13), U1.1 (I/O/GTS3), U4.17 (A17)
/A14: J1.45 (A14), U1.27 (I/O/GCK3), U4.18 (A7)
/A15: J1.46 (A15), U1.95, U4.19 (A6)
/A16: J1.47 (A16), U1.30, U4.20 (A5)
/A17: J1.48 (A17), U1.28, U4.21 (A4)
/A18: J1.49 (A18), U1.33, U4.25 (A0)
/A19: J1.50 (A19), U1.32, U4.23 (A2)
/A20: J1.51 (A20), U1.93, U4.48 (A16)
/A21: J1.53 (A21), U1.34, U4.10 (A20)
/A22: J1.54 (A22), U1.92
/A23: J1.55 (A23), U1.91
/CLK7: J1.15 (CLK), U1.22 (I/O/GCK1)
/D0: J1.5 (D0), U1.46, U4.45 (DQ15/A20)
/D1: J1.4 (D1), U1.43, U4.43 (DQ14)
/D2: J1.3 (D2), U1.42, U4.41 (DQ13)
/D3: J1.2 (D3), U1.85, U4.39 (DQ12)
/D4: J1.1 (D4), U1.41, U4.36 (DQ11)
/D5: J1.68 (D5), U1.86, U4.34 (DQ10)
/D6: J1.67 (D6), U1.40, U4.32 (DQ9)
/D7: J1.66 (D7), U1.36, U4.30 (DQ8)
/D8: J1.65 (D8), U1.76, U4.29 (DQ0)
/D9: J1.64 (D9), U1.37, U4.31 (DQ1)
/D10: J1.63 (D10), U1.77, U4.33 (DQ2)
/D11: J1.62 (D11), U1.90, U4.35 (DQ3)
/D12: J1.61 (D12), U1.82, U4.38 (DQ4)
/D13: J1.60 (D13), U1.87, U4.40 (DQ5)
/D14: J1.59 (D14), U1.89, U4.42 (DQ6)
/D15: J1.58 (D15), U1.39, U4.44 (DQ7)
/E: JP3.1 (A), R1.2, U1.24
/M68K_E: J1.22 (E), JP3.2 (B)
/PI_A0: J2.3 (SDA/GPIO2), U1.81
/PI_A1: J2.5 (SCL/GPIO3), U1.80
/PI_CLK: J2.7 (GCLK0/GPIO4), U1.78
/PI_IPL_0: J2.28 (ID_SC/GPIO1), U1.63
/PI_RD: J2.31 (GCLK2/GPIO6), U1.58
/PI_RESET: J2.29 (GCLK1/GPIO5), U1.60
/PI_TXN_IN_PROCESS: J2.27 (ID_SD/GPIO0), U1.61
/PI_WR: J2.26 (~CE1/GPIO7), U1.64
/RAMCE: U1.35, U4.12 (CE2)
/RW: J1.9 (R/W), U1.19, U4.11 (WE#)
/SD0: J2.24 (~CE0/GPIO8), U1.66
/SD1: J2.21 (MISO0/GPIO9), U1.67
/SD2: J2.19 (MOSI0/GPIO10), U1.68
/SD3: J2.23 (SCLK0/GPIO11), U1.65
/SD4: J2.32 (PWM0/GPIO12), U1.59
/SD5: J2.33 (PWM1/GPIO13), U1.56
/SD6: J2.8 (GPIO14/TXD), U1.79
/SD7: J2.10 (GPIO15/RXD), U1.74
/SD8: J2.36 (GPIO16), U1.55
/SD9: J2.11 (GPIO17), U1.72
/SD10: J2.12 (GPIO18/PWM0), U1.73
/SD11: J2.35 (GPIO19/MISO1), U1.54
/SD12: J2.38 (GPIO20/MOSI1), U1.53
/SD13: J2.40 (GPIO21/SCLK1), U1.52
/SD14: J2.15 (GPIO22), U1.70
/SD15: J2.16 (GPIO23), U1.71
/TCK: J2.37 (GPIO26), J3.6, U1.48 (TCK)
/TDI: J2.13 (GPIO27), J3.3, U1.45 (TDI)
/TDO: J2.22 (GPIO25), J3.5, U1.83 (TDO)
/TMS: J2.18 (GPIO24), J3.4, U1.47 (TMS)
/_AS: J1.6 (AS), U1.49
/_BERR: J1.24 (BERR)
/_BG: J1.11 (BG), R2.1, U1.16
/_BR: J1.13 (BR), U1.15
/_DTACK: J1.10 (DTACK), U1.50
/_HALT: J1.19 (HALT), U1.11
/_IPL0: J1.27 (IPL0), U1.13
/_IPL1: J1.26 (IPL1), U1.14
/_IPL2: J1.25 (IPL2), U1.12
/_LDS: J1.8 (LDS), U1.18, U4.14 (BHE#)
/_M68K_BGACK: J1.12 (BGACK)
/_M68K_VMA: J1.21 (VMA), JP2.2 (B)
/_M68K_VPA: J1.23 (VPA), JP4.2 (B)
/_OVR: J4.1, U1.25
/_RST: J1.20 (RESET), U1.99 (I/O/GSR)
/_UDS: J1.7 (UDS), U1.17, U4.15 (BLE#)
/_VMA: JP2.1 (A), U1.23 (I/O/GCK2)
/_VPA: JP4.1 (A), U1.20
GND: C1.2, C2.2, C3.2, C4.2, C5.2, C6.2, C7.2, C8.2, C9.2, C10.2, J1.16 (GND), J1.17 (GND), J1.56 (GND), J1.57 (GND), J2.6 (GND), J2.9 (GND), J2.14 (GND), J2.20 (GND), J2.25 (GND), J2.30 (GND), J2.34 (GND), J2.39 (GND), J3.1, J5.1, R2.2, U1.21 (GND), U1.31 (GND), U1.44 (GND), U1.62 (GND), U1.69 (GND), U1.75 (GND), U1.84 (GND), U1.100 (GND), U2.2 (GND), U3.1 (GND), U4.26 (CE1#), U4.27 (VSS), U4.28 (OE#), U4.46 (VSS)
unnamed: J2.1 (3V3), J2.17 (3V3), JP1.2 (B)

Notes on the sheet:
CLK7 should be connected to GCK
Pi : 24 I/O + 4 prog SD0-15 SA0-2 AUX0-1 PICLK TDI TDO TCK TMS * SOE SWE
RAM decoupling
PCB ready for CY62177ESL however due to the price of this chip only CY62167ELL are tested. Stay away from low voltage versions of this chip.
Not use since the PLCC 68000 must be present
Pull up/down for 68000 detection and bus control
alternative footprint
pi 3.3v regulator should not be powerful enough
Warning : LDS, UDS and data lines are swapped to simplify routing
TQFP 100 = 81 IO pins
68000 : 53 I/O + 3 bus control + 1 BERR + 3 FC D0-15 A1-23 AS R/W UDS LDS DTACK RESET HALT E CLK IPL0-2 VPA VMA BR BG BGACK * FC0-2 * BERR *
PI_CLK is not used in Pistorm'X firmware

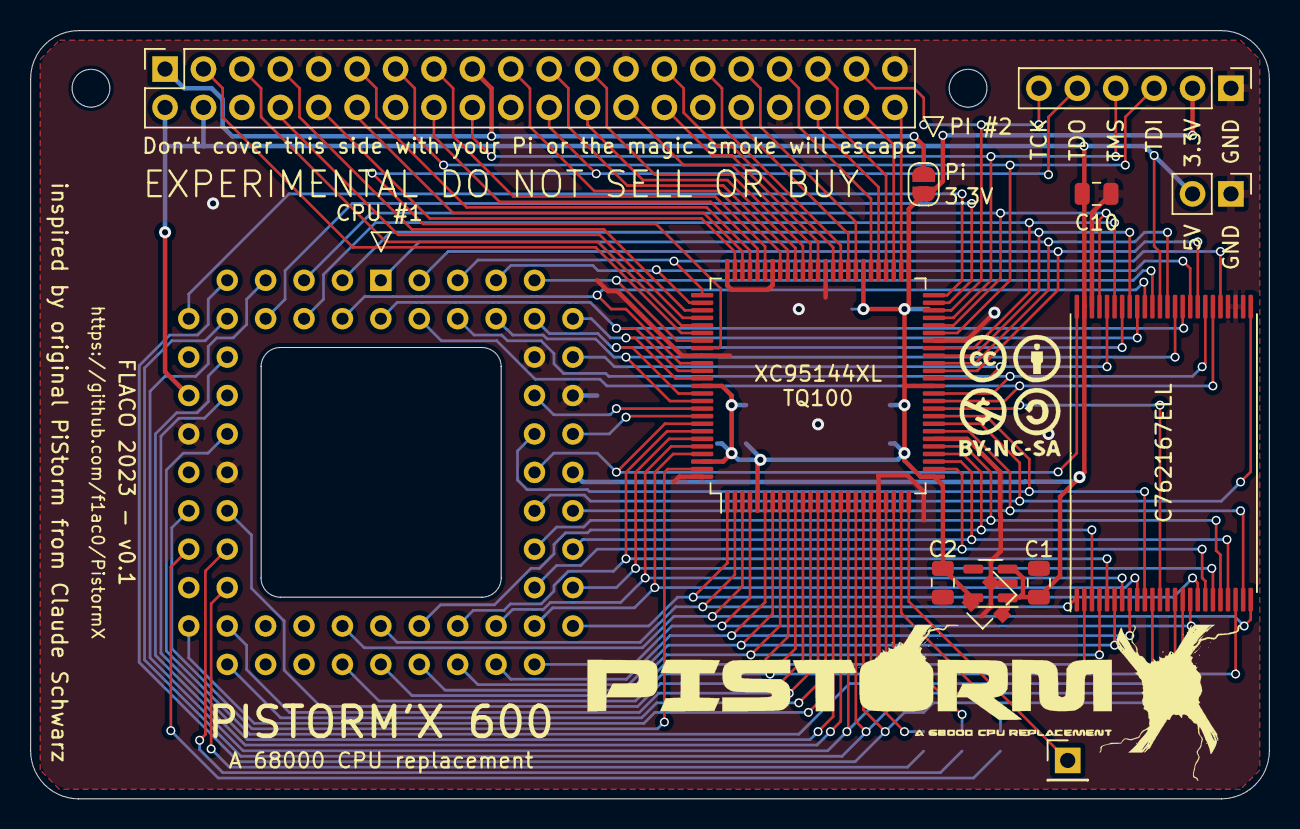
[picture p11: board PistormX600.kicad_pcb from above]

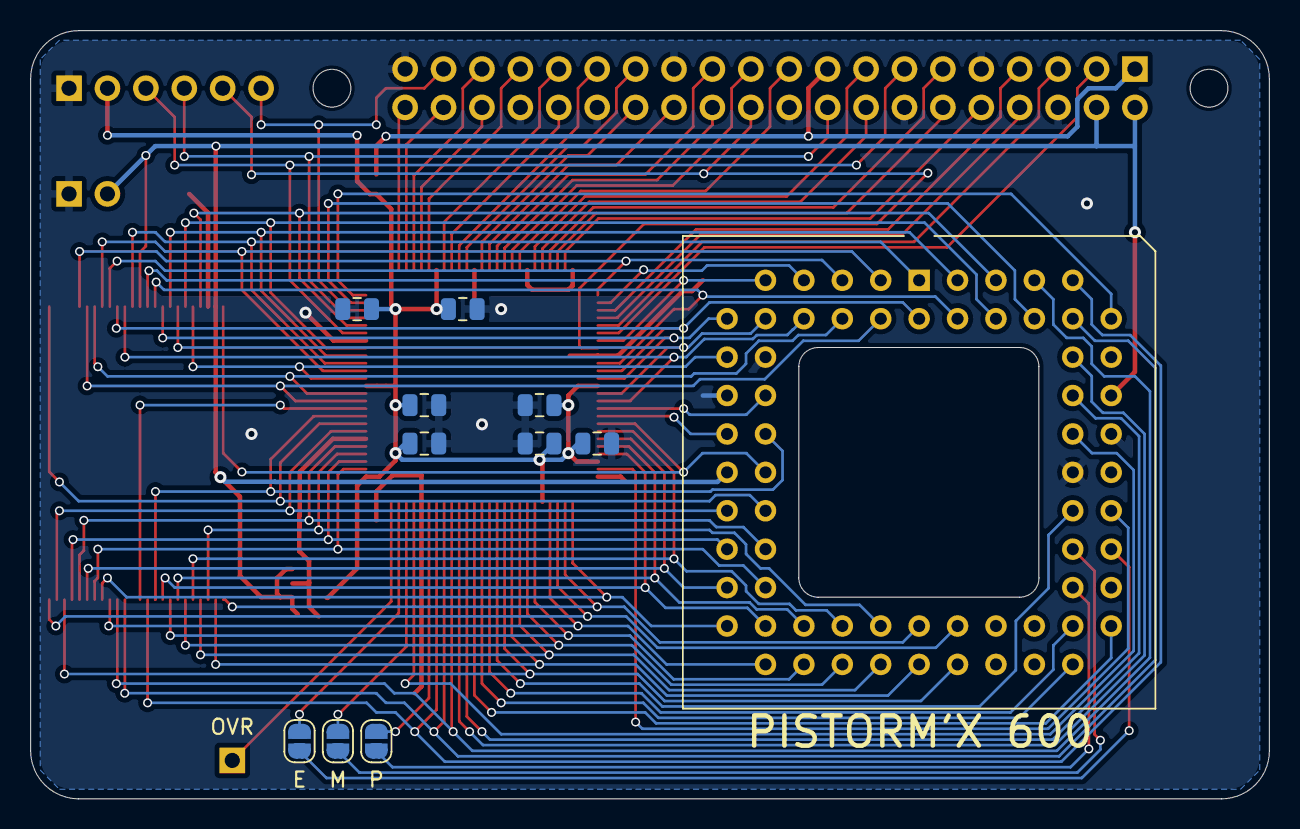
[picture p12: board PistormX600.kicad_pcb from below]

Board: 2 copper layers, 81.9 x 50.8 mm, 27 parts (13 on the bottom side), 92 nets.

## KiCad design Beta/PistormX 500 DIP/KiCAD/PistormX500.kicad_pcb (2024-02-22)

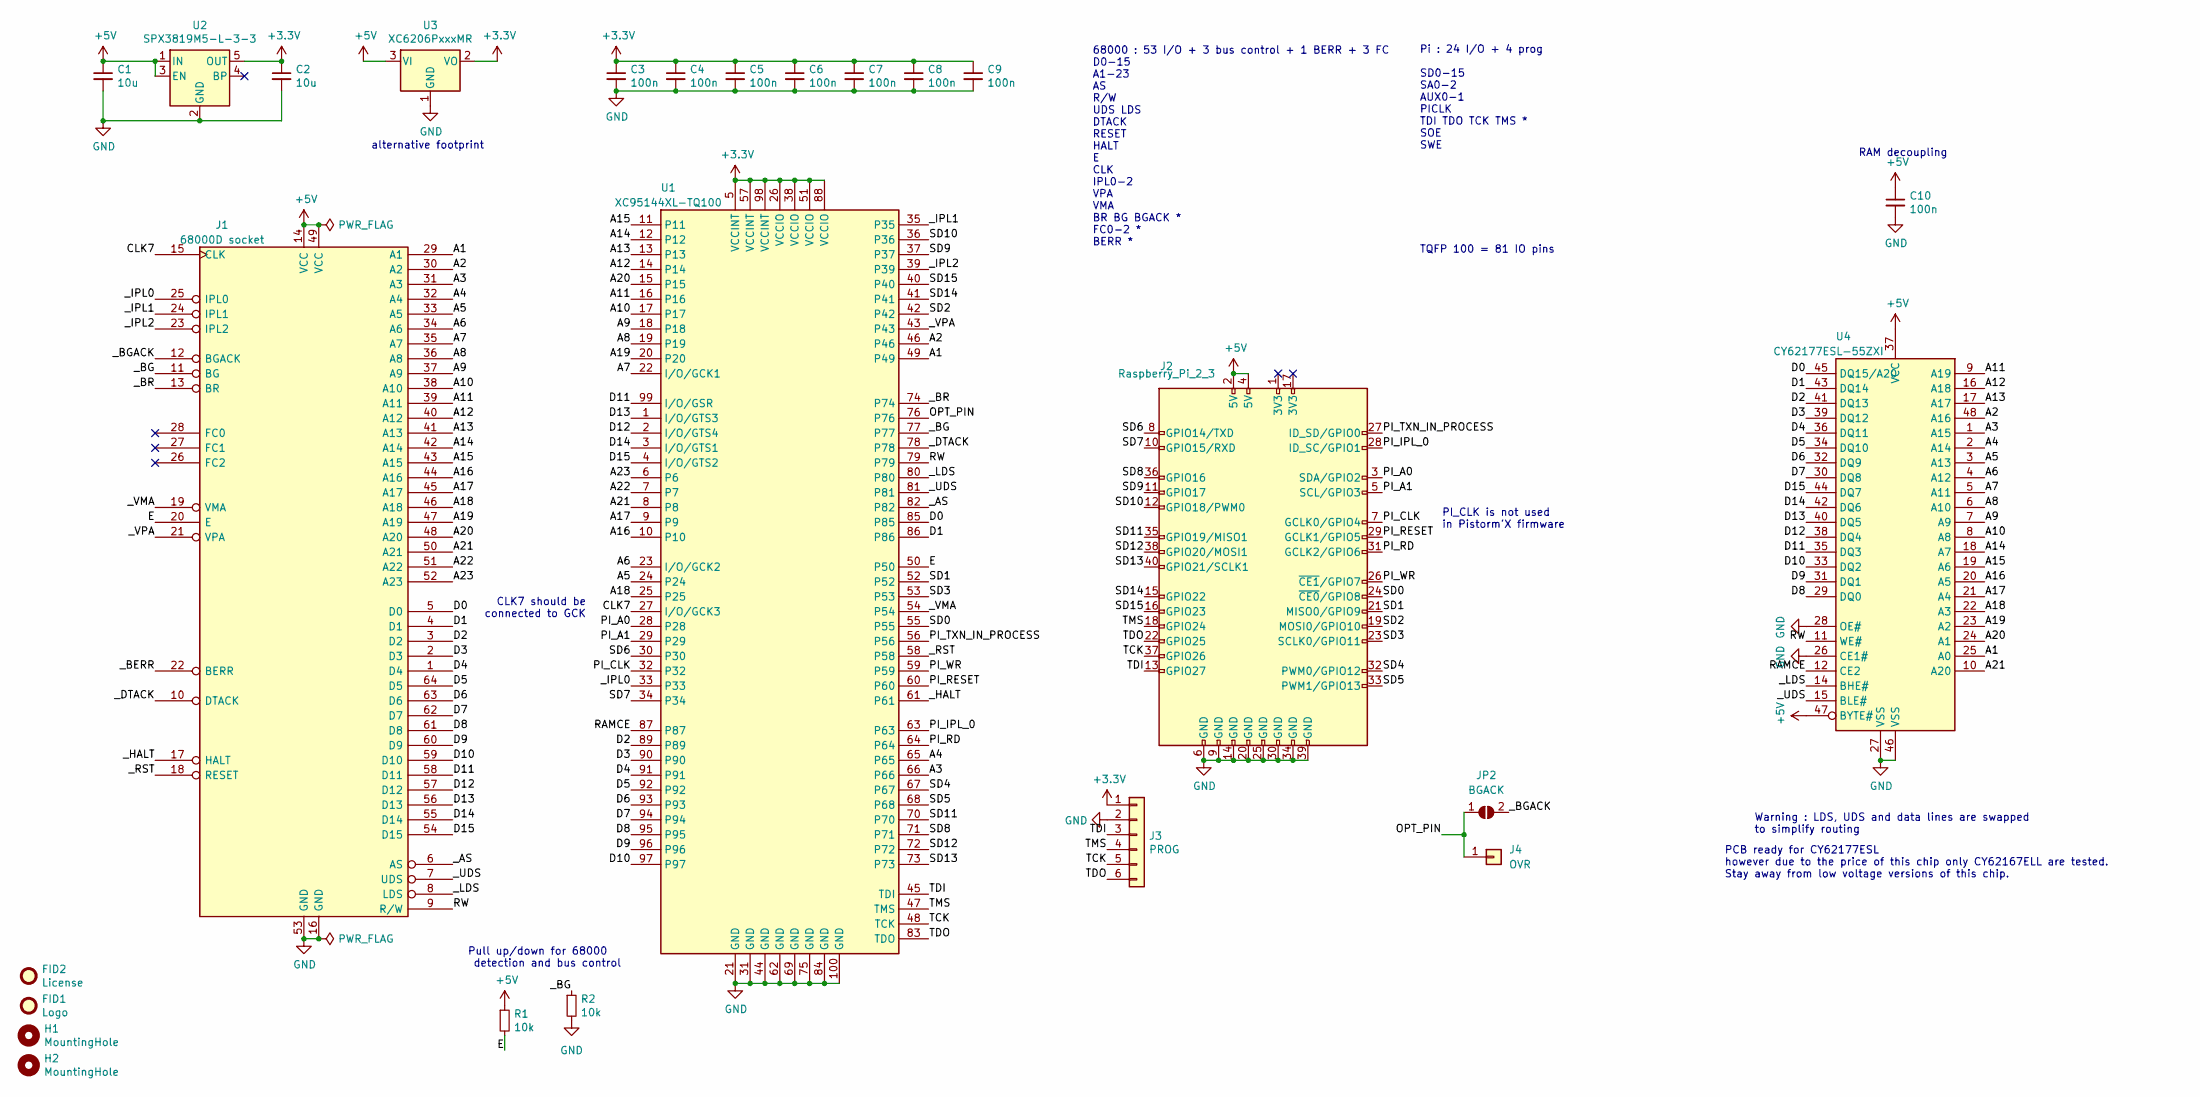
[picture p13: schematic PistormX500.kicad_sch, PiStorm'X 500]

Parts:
C1, C2: 10u; C_0805_2012Metric
C3, C4, C5, C6, C7, C8, C9, C10: 100n; C_0805_2012Metric
FID1: Logo; PIC_PistormX_43x10mm
FID2: License; CC_BY_NC_SA_square_silkscreen
H1, H2: MountingHole; MountingHole_2.5mm
J1: 68000D socket; DIP-64_W22.86mm_BigPads1.4
J2: Raspberry_Pi_2_3; PinSocket_2x20_P2.54mm_Vertical
J3: PROG; PinHeader_1x06_P2.54mm_Vertical
J4: OVR; PinHeader_1x01_P2.54mm_Vertical
JP2: BGACK; SolderJumper-2_P1.3mm_Open_RoundedPad1.0x1.5mm
R1, R2: 10k; R_0805_2012Metric
U1: XC95144XL-TQ100; TQFP-100_14x14mm_P0.5mm
U2: SPX3819M5-L-3-3; SOT-23-5
U3: XC6206PxxxMR; SOT-23
U4: CY62177ESL-55ZXI; TSOP-I-48_18.4x12mm_P0.5mm

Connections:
+3.3V: C2.1, C3.1, C4.1, C5.1, C6.1, C7.1, C8.1, C9.1, J3.1, U1.5 (VCCINT), U1.26 (VCCIO), U1.38 (VCCIO), U1.51 (VCCIO), U1.57 (VCCINT), U1.88 (VCCIO), U1.98 (VCCINT), U2.5 (OUT), U3.2 (VO)
+5V: C1.1, C10.1, J1.14 (VCC), J1.49 (VCC), J2.2 (5V), J2.4 (5V), R1.1, U2.1 (IN), U2.3 (EN), U3.3 (VI), U4.37 (VCC), U4.47 (BYTE#)
/A1: J1.29 (A1), U1.49, U4.25 (A0)
/A2: J1.30 (A2), U1.46, U4.48 (A16)
/A3: J1.31 (A3), U1.66, U4.1 (A15)
/A4: J1.32 (A4), U1.65, U4.2 (A14)
/A5: J1.33 (A5), U1.24, U4.3 (A13)
/A6: J1.34 (A6), U1.23 (I/O/GCK2), U4.4 (A12)
/A7: J1.35 (A7), U1.22 (I/O/GCK1), U4.5 (A11)
/A8: J1.36 (A8), U1.19, U4.6 (A10)
/A9: J1.37 (A9), U1.18, U4.7 (A9)
/A10: J1.38 (A10), U1.17, U4.8 (A8)
/A11: J1.39 (A11), U1.16, U4.9 (A19)
/A12: J1.40 (A12), U1.14, U4.16 (A18)
/A13: J1.41 (A13), U1.13, U4.17 (A17)
/A14: J1.42 (A14), U1.12, U4.18 (A7)
/A15: J1.43 (A15), U1.11, U4.19 (A6)
/A16: J1.44 (A16), U1.10, U4.20 (A5)
/A17: J1.45 (A17), U1.9, U4.21 (A4)
/A18: J1.46 (A18), U1.25, U4.22 (A3)
/A19: J1.47 (A19), U1.20, U4.23 (A2)
/A20: J1.48 (A20), U1.15, U4.24 (A1)
/A21: J1.50 (A21), U1.8, U4.10 (A20)
/A22: J1.51 (A22), U1.7
/A23: J1.52 (A23), U1.6
/CLK7: J1.15 (CLK), U1.27 (I/O/GCK3)
/D0: J1.5 (D0), U1.85, U4.45 (DQ15/A20)
/D1: J1.4 (D1), U1.86, U4.43 (DQ14)
/D2: J1.3 (D2), U1.89, U4.41 (DQ13)
/D3: J1.2 (D3), U1.90, U4.39 (DQ12)
/D4: J1.1 (D4), U1.91, U4.36 (DQ11)
/D5: J1.64 (D5), U1.92, U4.34 (DQ10)
/D6: J1.63 (D6), U1.93, U4.32 (DQ9)
/D7: J1.62 (D7), U1.94, U4.30 (DQ8)
/D8: J1.61 (D8), U1.95, U4.29 (DQ0)
/D9: J1.60 (D9), U1.96, U4.31 (DQ1)
/D10: J1.59 (D10), U1.97, U4.33 (DQ2)
/D11: J1.58 (D11), U1.99 (I/O/GSR), U4.35 (DQ3)
/D12: J1.57 (D12), U1.2 (I/O/GTS4), U4.38 (DQ4)
/D13: J1.56 (D13), U1.1 (I/O/GTS3), U4.40 (DQ5)
/D14: J1.55 (D14), U1.3 (I/O/GTS1), U4.42 (DQ6)
/D15: J1.54 (D15), U1.4 (I/O/GTS2), U4.44 (DQ7)
/E: J1.20 (E), R1.2, U1.50
/OPT_PIN: J4.1, JP2.1 (A), U1.76
/PI_A0: J2.3 (SDA/GPIO2), U1.28
/PI_A1: J2.5 (SCL/GPIO3), U1.29
/PI_CLK: J2.7 (GCLK0/GPIO4), U1.32
/PI_IPL_0: J2.28 (ID_SC/GPIO1), U1.63
/PI_RD: J2.31 (GCLK2/GPIO6), U1.64
/PI_RESET: J2.29 (GCLK1/GPIO5), U1.60
/PI_TXN_IN_PROCESS: J2.27 (ID_SD/GPIO0), U1.56
/PI_WR: J2.26 (~CE1/GPIO7), U1.59
/RAMCE: U1.87, U4.12 (CE2)
/RW: J1.9 (R/W), U1.79, U4.11 (WE#)
/SD0: J2.24 (~CE0/GPIO8), U1.55
/SD1: J2.21 (MISO0/GPIO9), U1.52
/SD2: J2.19 (MOSI0/GPIO10), U1.42
/SD3: J2.23 (SCLK0/GPIO11), U1.53
/SD4: J2.32 (PWM0/GPIO12), U1.67
/SD5: J2.33 (PWM1/GPIO13), U1.68
/SD6: J2.8 (GPIO14/TXD), U1.30
/SD7: J2.10 (GPIO15/RXD), U1.34
/SD8: J2.36 (GPIO16), U1.71
/SD9: J2.11 (GPIO17), U1.37
/SD10: J2.12 (GPIO18/PWM0), U1.36
/SD11: J2.35 (GPIO19/MISO1), U1.70
/SD12: J2.38 (GPIO20/MOSI1), U1.72
/SD13: J2.40 (GPIO21/SCLK1), U1.73
/SD14: J2.15 (GPIO22), U1.41
/SD15: J2.16 (GPIO23), U1.40
/TCK: J2.37 (GPIO26), J3.5, U1.48 (TCK)
/TDI: J2.13 (GPIO27), J3.3, U1.45 (TDI)
/TDO: J2.22 (GPIO25), J3.6, U1.83 (TDO)
/TMS: J2.18 (GPIO24), J3.4, U1.47 (TMS)
/_AS: J1.6 (AS), U1.82
/_BERR: J1.22 (BERR)
/_BG: J1.11 (BG), R2.1, U1.77
/_BGACK: J1.12 (BGACK), JP2.2 (B)
/_BR: J1.13 (BR), U1.74
/_DTACK: J1.10 (DTACK), U1.78
/_HALT: J1.17 (HALT), U1.61
/_IPL0: J1.25 (IPL0), U1.33
/_IPL1: J1.24 (IPL1), U1.35
/_IPL2: J1.23 (IPL2), U1.39
/_LDS: J1.8 (LDS), U1.80, U4.14 (BHE#)
/_RST: J1.18 (RESET), U1.58
/_UDS: J1.7 (UDS), U1.81, U4.15 (BLE#)
/_VMA: J1.19 (VMA), U1.54
/_VPA: J1.21 (VPA), U1.43
GND: C1.2, C2.2, C3.2, C4.2, C5.2, C6.2, C7.2, C8.2, C9.2, C10.2, J1.16 (GND), J1.53 (GND), J2.6 (GND), J2.9 (GND), J2.14 (GND), J2.20 (GND), J2.25 (GND), J2.30 (GND), J2.34 (GND), J2.39 (GND), J3.2, R2.2, U1.21 (GND), U1.31 (GND), U1.44 (GND), U1.62 (GND), U1.69 (GND), U1.75 (GND), U1.84 (GND), U1.100 (GND), U2.2 (GND), U3.1 (GND), U4.26 (CE1#), U4.27 (VSS), U4.28 (OE#), U4.46 (VSS)

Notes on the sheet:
CLK7 should be connected to GCK
Pi : 24 I/O + 4 prog SD0-15 SA0-2 AUX0-1 PICLK TDI TDO TCK TMS * SOE SWE
PCB ready for CY62177ESL however due to the price of this chip only CY62167ELL are tested. Stay away from low voltage versions of this chip.
Pull up/down for 68000 detection and bus control
alternative footprint
Warning : LDS, UDS and data lines are swapped to simplify routing
TQFP 100 = 81 IO pins
68000 : 53 I/O + 3 bus control + 1 BERR + 3 FC D0-15 A1-23 AS R/W UDS LDS DTACK RESET HALT E CLK IPL0-2 VPA VMA BR BG BGACK * FC0-2 * BERR *
RAM decoupling
PI_CLK is not used in Pistorm'X firmware

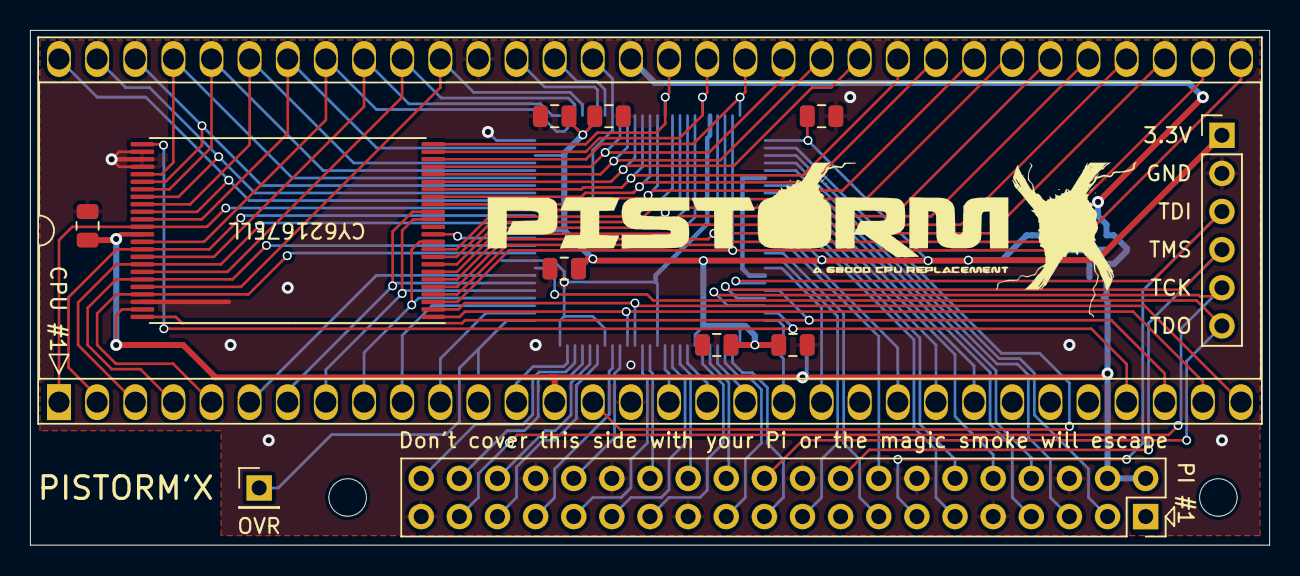
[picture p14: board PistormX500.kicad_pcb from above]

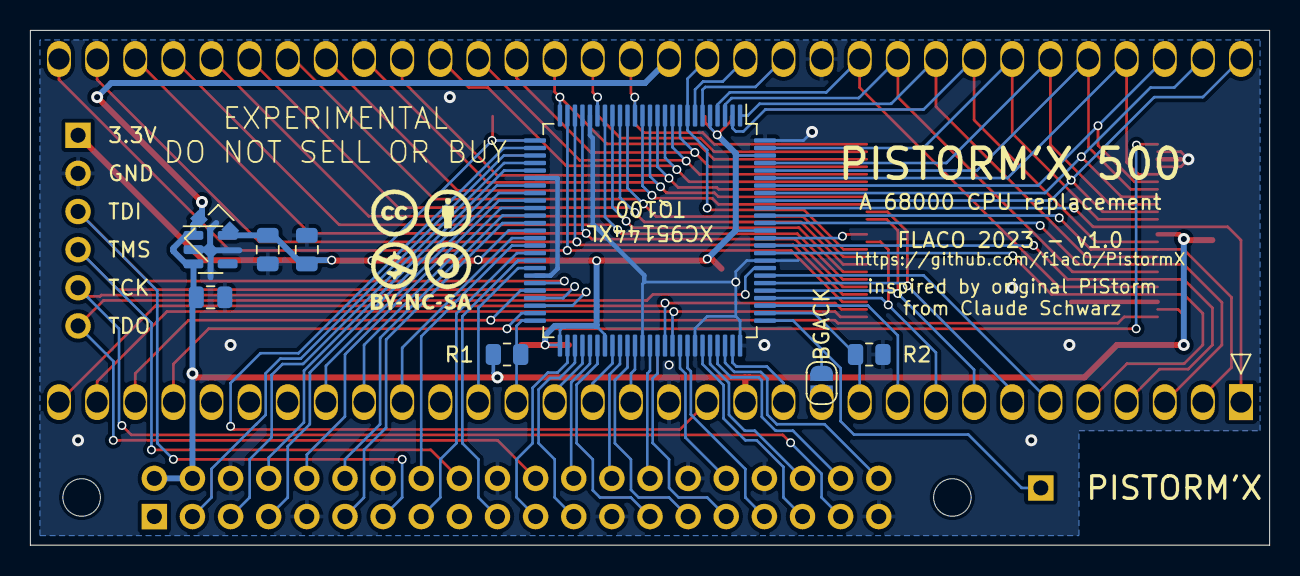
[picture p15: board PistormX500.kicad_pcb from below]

Board: 2 copper layers, 82.6 x 34.3 mm, 25 parts (10 on the bottom side), 89 nets.

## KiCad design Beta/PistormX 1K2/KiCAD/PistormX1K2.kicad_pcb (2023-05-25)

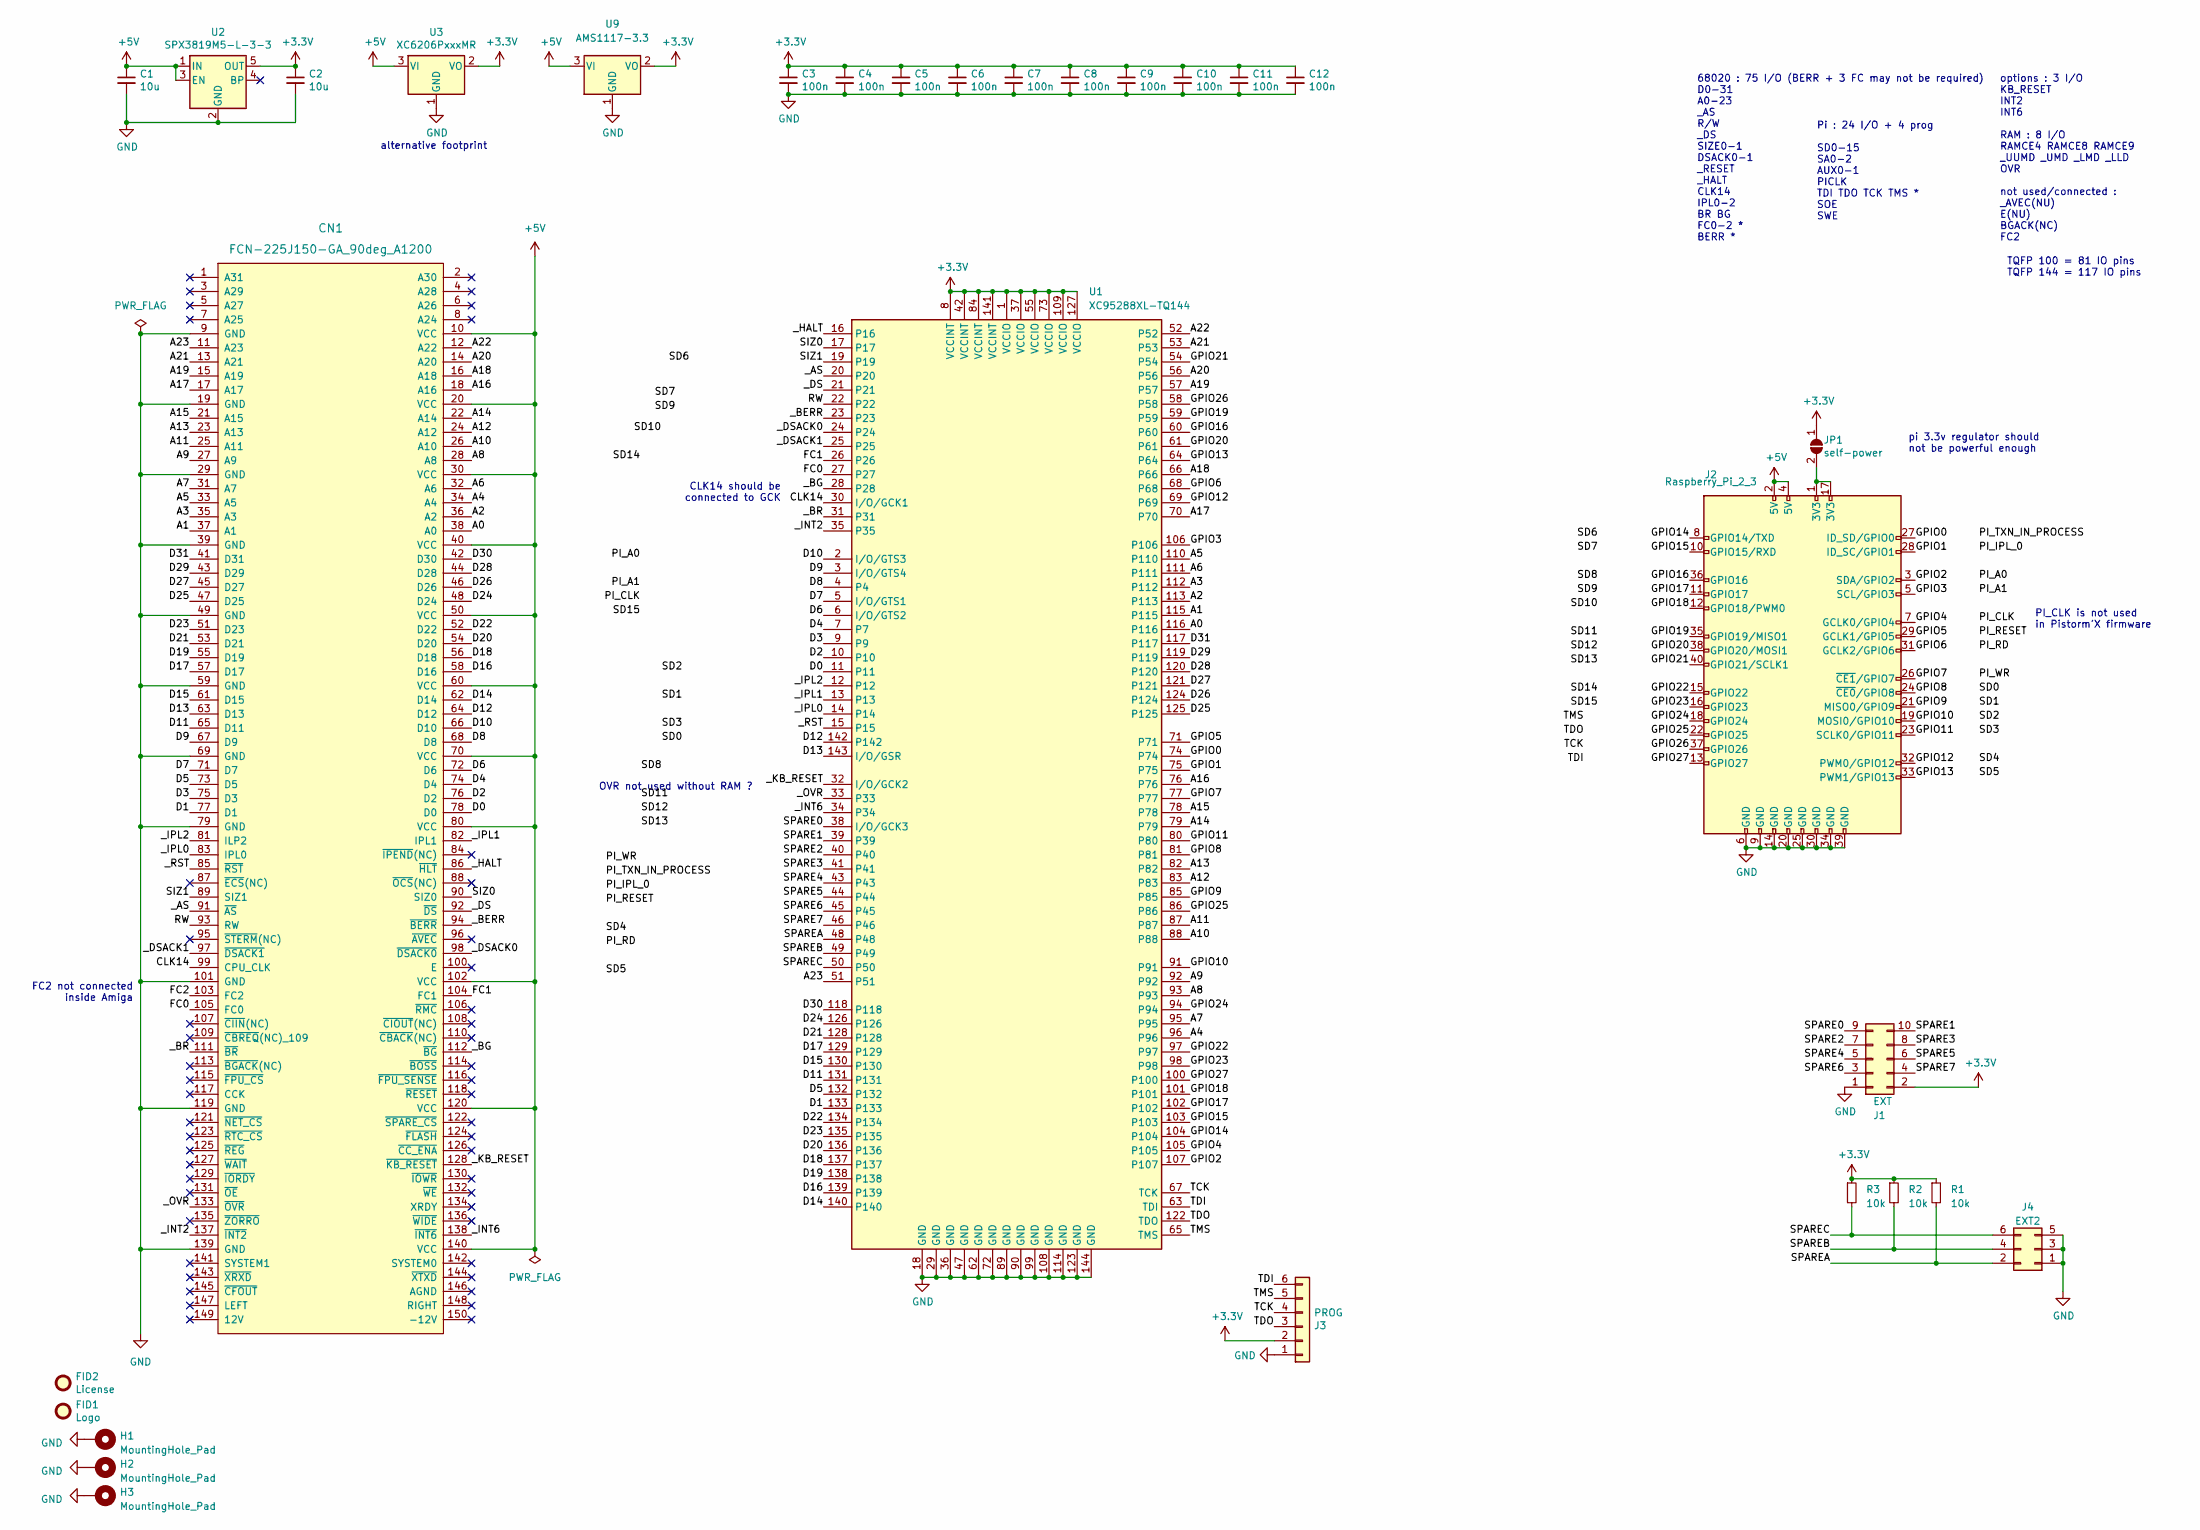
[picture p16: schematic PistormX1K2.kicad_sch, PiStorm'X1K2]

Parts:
C1, C2: 10u; C_0805_2012Metric
C3, C4, C5, C6, C7, C8, C9, C10, C11, C12: 100n; C_0603_1608Metric
CN1: FCN-225J150-GA_90deg_A1200
FID1: Logo; PIC_PistormX_43x10mm
FID2: License; CC_BY_NC_SA_square_silkscreen
H1, H2, H3: MountingHole_Pad; MountingHole_2.7mm_M2.5_DIN965_Pad
J1: EXT; PinHeader_2x05_P2.54mm_Vertical
J2: Raspberry_Pi_2_3; PinSocket_2x20_P2.54mm_Vertical_SMD_BottomEntry
J3: PROG; PinHeader_1x06_P2.54mm_Vertical
J4: EXT2; PinHeader_2x03_P2.54mm_Vertical
JP1: self-power; SolderJumper-2_P1.3mm_Open_RoundedPad1.0x1.5mm
R1, R2, R3: 10k; R_0805_2012Metric
U1: XC95288XL-TQ144; TQFP-144_20x20mm_P0.5mm
U2: SPX3819M5-L-3-3; SOT-23-5
U3: XC6206PxxxMR; SOT-23
U9: AMS1117-3.3; SOT-223-3_TabPin2

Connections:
+3.3V: C2.1, C3.1, C4.1, C5.1, C6.1, C7.1, C8.1, C9.1, C10.1, C11.1, C12.1, J1.2, J3.2, JP1.1 (A), R1.1, R2.1, R3.1, U1.1 (VCCIO), U1.8 (VCCINT), U1.37 (VCCIO), U1.42 (VCCINT), U1.55 (VCCIO), U1.73 (VCCIO), U1.84 (VCCINT), U1.109 (VCCIO), U1.127 (VCCIO), U1.141 (VCCINT), U2.5 (OUT), U3.2 (VO), U9.2 (VO)
+5V: C1.1, CN1.10 (VCC), CN1.20 (VCC), CN1.30 (VCC), CN1.40 (VCC), CN1.50 (VCC), CN1.60 (VCC), CN1.70 (VCC), CN1.80 (VCC), CN1.102 (VCC), CN1.120 (VCC), CN1.140 (VCC), J2.2 (5V), J2.4 (5V), U2.1 (IN), U2.3 (EN), U3.3 (VI), U9.3 (VI)
/A0: CN1.38 (A0), U1.116
/A1: CN1.37 (A1), U1.115
/A2: CN1.36 (A2), U1.113
/A3: CN1.35 (A3), U1.112
/A4: CN1.34 (A4), U1.96
/A5: CN1.33 (A5), U1.110
/A6: CN1.32 (A6), U1.111
/A7: CN1.31 (A7), U1.95
/A8: CN1.28 (A8), U1.93
/A9: CN1.27 (A9), U1.92
/A10: CN1.26 (A10), U1.88
/A11: CN1.25 (A11), U1.87
/A12: CN1.24 (A12), U1.83
/A13: CN1.23 (A13), U1.82
/A14: CN1.22 (A14), U1.79
/A15: CN1.21 (A15), U1.78
/A16: CN1.18 (A16), U1.76
/A17: CN1.17 (A17), U1.70
/A18: CN1.16 (A18), U1.66
/A19: CN1.15 (A19), U1.57
/A20: CN1.14 (A20), U1.56
/A21: CN1.13 (A21), U1.53
/A22: CN1.12 (A22), U1.52
/A23: CN1.11 (A23), U1.51
/CLK14: CN1.99 (CPU_CLK), U1.30 (I/O/GCK1)
/D0: CN1.78 (D0), U1.11
/D1: CN1.77 (D1), U1.133
/D2: CN1.76 (D2), U1.10
/D3: CN1.75 (D3), U1.9
/D4: CN1.74 (D4), U1.7
/D5: CN1.73 (D5), U1.132
/D6: CN1.72 (D6), U1.6 (I/O/GTS2)
/D7: CN1.71 (D7), U1.5 (I/O/GTS1)
/D8: CN1.68 (D8), U1.4
/D9: CN1.67 (D9), U1.3 (I/O/GTS4)
/D10: CN1.66 (D10), U1.2 (I/O/GTS3)
/D11: CN1.65 (D11), U1.131
/D12: CN1.64 (D12), U1.142
/D13: CN1.63 (D13), U1.143 (I/O/GSR)
/D14: CN1.62 (D14), U1.140
/D15: CN1.61 (D15), U1.130
/D16: CN1.58 (D16), U1.139
/D17: CN1.57 (D17), U1.129
/D18: CN1.56 (D18), U1.137
/D19: CN1.55 (D19), U1.138
/D20: CN1.54 (D20), U1.136
/D21: CN1.53 (D21), U1.128
/D22: CN1.52 (D22), U1.134
/D23: CN1.51 (D23), U1.135
/D24: CN1.48 (D24), U1.126
/D25: CN1.47 (D25), U1.125
/D26: CN1.46 (D26), U1.124
/D27: CN1.45 (D27), U1.121
/D28: CN1.44 (D28), U1.120
/D29: CN1.43 (D29), U1.119
/D30: CN1.42 (D30), U1.118
/D31: CN1.41 (D31), U1.117
/FC0: CN1.105 (FC0), U1.27
/FC1: CN1.104 (FC1), U1.26
/FC2: CN1.103 (FC2)
/GPIO0: J2.27 (ID_SD/GPIO0), U1.74
/GPIO1: J2.28 (ID_SC/GPIO1), U1.75
/GPIO2: J2.3 (SDA/GPIO2), U1.107
/GPIO3: J2.5 (SCL/GPIO3), U1.106
/GPIO4: J2.7 (GCLK0/GPIO4), U1.105
/GPIO5: J2.29 (GCLK1/GPIO5), U1.71
/GPIO6: J2.31 (GCLK2/GPIO6), U1.68
/GPIO7: J2.26 (~CE1/GPIO7), U1.77
/GPIO8: J2.24 (~CE0/GPIO8), U1.81
/GPIO9: J2.21 (MISO0/GPIO9), U1.85
/GPIO10: J2.19 (MOSI0/GPIO10), U1.91
/GPIO11: J2.23 (SCLK0/GPIO11), U1.80
/GPIO12: J2.32 (PWM0/GPIO12), U1.69
/GPIO13: J2.33 (PWM1/GPIO13), U1.64
/GPIO14: J2.8 (GPIO14/TXD), U1.104
/GPIO15: J2.10 (GPIO15/RXD), U1.103
/GPIO16: J2.36 (GPIO16), U1.60
/GPIO17: J2.11 (GPIO17), U1.102
/GPIO18: J2.12 (GPIO18/PWM0), U1.101
/GPIO19: J2.35 (GPIO19/MISO1), U1.59
/GPIO20: J2.38 (GPIO20/MOSI1), U1.61
/GPIO21: J2.40 (GPIO21/SCLK1), U1.54
/GPIO22: J2.15 (GPIO22), U1.97
/GPIO23: J2.16 (GPIO23), U1.98
/GPIO24: J2.18 (GPIO24), U1.94
/GPIO25: J2.22 (GPIO25), U1.86
/GPIO26: J2.37 (GPIO26), U1.58
/GPIO27: J2.13 (GPIO27), U1.100
/RW: CN1.93 (RW), U1.22
/SIZ0: CN1.90 (SIZ0), U1.17
/SIZ1: CN1.89 (SIZ1), U1.19
/SPARE0: J1.9, U1.38 (I/O/GCK3)
/SPARE1: J1.10, U1.39
/SPARE2: J1.7, U1.40
/SPARE3: J1.8, U1.41
/SPARE4: J1.5, U1.43
/SPARE5: J1.6, U1.44
/SPARE6: J1.3, U1.45
/SPARE7: J1.4, U1.46
/SPAREA: J4.2, R1.2, U1.48
/SPAREB: J4.4, R2.2, U1.49
/SPAREC: J4.6, R3.2, U1.50
/TCK: J3.4, U1.67 (TCK)
/TDI: J3.6, U1.63 (TDI)
/TDO: J3.3, U1.122 (TDO)
/TMS: J3.5, U1.65 (TMS)
/_AS: CN1.91 (~AS), U1.20
/_BERR: CN1.94 (~BERR), U1.23
/_BG: CN1.112 (~BG), U1.28
/_BR: CN1.111 (~BR), U1.31
/_DS: CN1.92 (~DS), U1.21
/_DSACK0: CN1.98 (~DSACK0), U1.24
/_DSACK1: CN1.97 (~DSACK1), U1.25
/_HALT: CN1.86 (~HLT), U1.16
/_INT2: CN1.137 (~INT2), U1.35
/_INT6: CN1.138 (~INT6), U1.34
/_IPL0: CN1.83 (IPL0), U1.14
/_IPL1: CN1.82 (IPL1), U1.13
/_IPL2: CN1.81 (ILP2), U1.12
/_KB_RESET: CN1.128 (~KB_RESET), U1.32 (I/O/GCK2)
/_OVR: CN1.133 (~OVR), U1.33
/_RST: CN1.85 (~RST), U1.15
GND: C1.2, C2.2, C3.2, C4.2, C5.2, C6.2, C7.2, C8.2, C9.2, C10.2, C11.2, C12.2, CN1.9 (GND), CN1.19 (GND), CN1.29 (GND), CN1.39 (GND), CN1.49 (GND), CN1.59 (GND), CN1.69 (GND), CN1.79 (GND), CN1.101 (GND), CN1.119 (GND), CN1.139 (GND), H1.1, H2.1, H3.1, J1.1, J2.6 (GND), J2.9 (GND), J2.14 (GND), J2.20 (GND), J2.25 (GND), J2.30 (GND), J2.34 (GND), J2.39 (GND), J3.1, J4.1, J4.3, J4.5, U1.18 (GND), U1.29 (GND), U1.36 (GND), U1.47 (GND), U1.62 (GND), U1.72 (GND), U1.89 (GND), U1.90 (GND), U1.99 (GND), U1.108 (GND), U1.114 (GND), U1.123 (GND), U1.144 (GND), U2.2 (GND), U3.1 (GND), U9.1 (GND)
unnamed: J2.1 (3V3), J2.17 (3V3), JP1.2 (B)

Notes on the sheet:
CLK14 should be connected to GCK
Pi : 24 I/O + 4 prog SD0-15 SA0-2 AUX0-1 PICLK TDI TDO TCK TMS * SOE SWE
OVR not used without RAM ?
FC2 not connected inside Amiga
alternative footprint
pi 3.3v regulator should not be powerful enough
TQFP 100 = 81 IO pins TQFP 144 = 117 IO pins
68020 : 75 I/O (BERR + 3 FC may not be required) D0-31 A0-23 _AS R/W _DS SIZE0-1 DSACK0-1 _RESET _HALT CLK14 IPL0-2 BR BG FC0-2 * BERR *
options : 3 I/O KB_RESET INT2 INT6 RAM : 8 I/O RAMCE4 RAMCE8 RAMCE9 _UUMD _UMD _LMD _LLD OVR not used/connected : _AVEC(NU) E(NU) BGACK(NC) FC2
PI_CLK is not used in Pistorm'X firmware

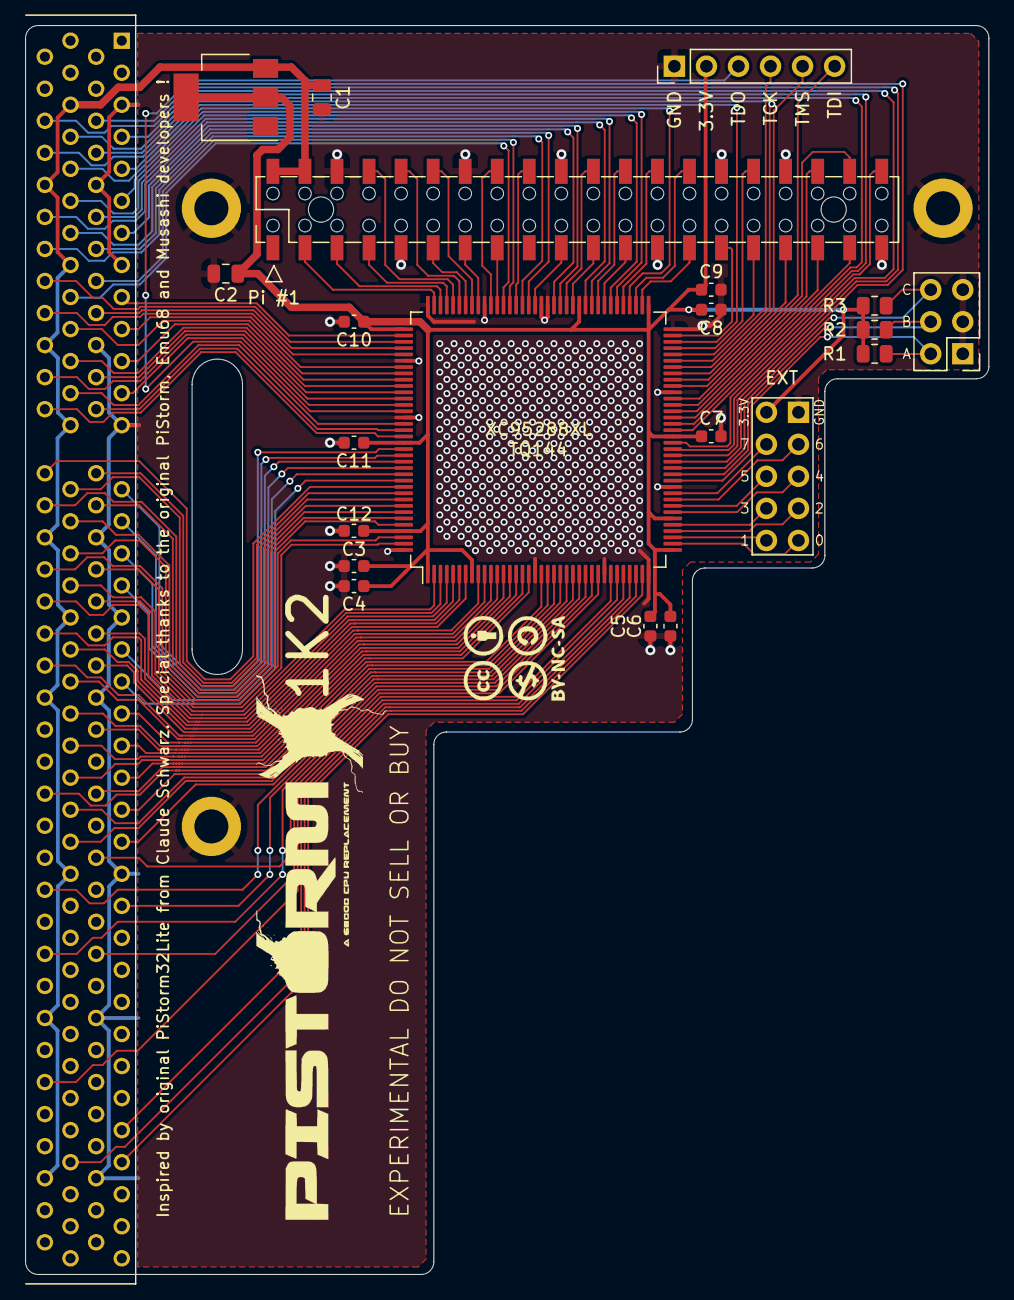
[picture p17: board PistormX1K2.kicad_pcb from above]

Board: 2 copper layers, 76.4 x 99.0 mm, 27 parts (1 on the bottom side), 125 nets.

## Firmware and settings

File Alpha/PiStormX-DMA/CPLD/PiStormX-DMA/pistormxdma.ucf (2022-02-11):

NET PI_TXN_IN_PROGRESS LOC=P37;
NET PI_IPL_ZERO LOC=P39;
NET PI_A<1> LOC=P10;
NET PI_A<0> LOC=P8;
//NET PI_CLK LOC=P23;
NET PI_RESET LOC=P40;
NET PI_RD LOC=P43;
NET PI_WR LOC=P36;
NET PI_D<15> LOC=P24;
NET PI_D<14> LOC=P20;
NET PI_D<13> LOC=P55;
NET PI_D<12> LOC=P54;
NET PI_D<11> LOC=P53;
NET PI_D<10> LOC=P18;
NET PI_D<9> LOC=P16;
NET PI_D<8> LOC=P50;
NET PI_D<7> LOC=P15;
NET PI_D<6> LOC=P13;
NET PI_D<5> LOC=P49;
NET PI_D<4> LOC=P42;
NET PI_D<3> LOC=P33;
NET PI_D<2> LOC=P28;
NET PI_D<1> LOC=P30;
NET PI_D<0> LOC=P34;

NET M68K_A<23> LOC=P52;
NET M68K_A<22> LOC=P46;
NET M68K_A<21> LOC=P41;
NET M68K_A<20> LOC=P35;
NET M68K_A<19> LOC=P32;
NET M68K_A<18> LOC=P29;
NET M68K_A<17> LOC=P27;
NET M68K_A<16> LOC=P25;
NET M68K_A<15> LOC=P22;
NET M68K_A<14> LOC=P19;
NET M68K_A<13> LOC=P17;
NET M68K_A<12> LOC=P14;
NET M68K_A<11> LOC=P12;
NET M68K_A<10> LOC=P11;
NET M68K_A<9> LOC=P9;
NET M68K_A<8> LOC=P7;
NET M68K_A<7> LOC=P6;
NET M68K_A<6> LOC=P85;
NET M68K_A<5> LOC=P86;
NET M68K_A<4> LOC=P87;
NET M68K_A<3> LOC=P89;
NET M68K_A<2> LOC=P90;
NET M68K_A<1> LOC=P91;
NET M68K_D<15> LOC=P56;
NET M68K_D<14> LOC=P58;
NET M68K_D<13> LOC=P59;
NET M68K_D<12> LOC=P60;
NET M68K_D<11> LOC=P61;
NET M68K_D<10> LOC=P63;
NET M68K_D<9> LOC=P64;
NET M68K_D<8> LOC=P65;
NET M68K_D<7> LOC=P66;
NET M68K_D<6> LOC=P67;
NET M68K_D<5> LOC=P68;
NET M68K_D<4> LOC=P70;
NET M68K_D<3> LOC=P71;
NET M68K_D<2> LOC=P72;
NET M68K_D<1> LOC=P73;
NET M68K_D<0> LOC=P74;
NET M68K_CLK LOC=P81;
//NET M68K_FC<2> LOC=P94;
//NET M68K_FC<1> LOC=P93;
//NET M68K_FC<0> LOC=P92;

NET M68K_AS_n LOC=P76;
NET M68K_UDS_n LOC=P77;
NET M68K_LDS_n LOC=P78;
NET M68K_RW LOC=P79;

NET M68K_DTACK_n LOC=P80;
//NET M68K_BERR_n LOC=P4;

NET M68K_VPA_n LOC=P3;
NET M68K_E LOC=P2;
NET M68K_VMA_n LOC=P1;

NET M68K_IPL_n<2> LOC=P95;
NET M68K_IPL_n<1> LOC=P96;
NET M68K_IPL_n<0> LOC=P97;

NET M68K_RESET_n LOC=P99;
NET M68K_HALT_n LOC=P82;

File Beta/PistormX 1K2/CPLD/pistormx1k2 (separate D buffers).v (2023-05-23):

/*
 * Pistorm'X for Xilinx CPLD, with integrated buffers and without 200MHz clock
 * 68K flavour, that can cohabit with the host original 68000 and can switch which one is activated by maintaining reset during at least 6 seconds
 * 2022 FLACO CC-BY-NC-SA
 * Inspired by original Pistorm, Copyright 2020 Claude Schwarz and Niklas Ekström, https://github.com/captain-amygdala/pistorm
 */

module pistormx1k2(
	output          PI_TXN_IN_PROGRESS, // GPIO0 //AUX0
//	output          PI_IPL_ZERO,        // GPIO1 //AUX1
	output  [2:0]   PI_IPL,        // GPIO1 //AUX1
	input   [2:0]   PI_A,       // GPIO[3..2]
	input           PI_RD,      // GPIO6
	input           PI_WR,      // GPIO7
	inout   [15:0]  PI_D,       // GPIO[23..8]
	output          PI_RESET_n, // GPIO5
   input           PI_SER_DAT,
   input           PI_SER_CLK,
	 
	output  [23:0]	 M68K_A,
	inout   [31:0]	 M68K_D,
	input           M68K_CLK,
	output  [1:0]   M68K_FC,   // PU on Amiga MB ; FC2 not connected inside A1200
	
	inout           M68K_AS_n,  // PU on Amiga MB
	output          M68K_DS_n,  // PU on Amiga MB
	output  [1:0]   M68K_SIZ, // PU on Amiga MB
	output          M68K_RW,    // PU on Amiga MB

	input   [1:0]   M68K_DSACK_n,
	input           M68K_BERR_n,

//	input           M68K_E,     //  clock 1 tick is 1.41 microseconds

	input   [2:0]   M68K_IPL_n,

	inout           M68K_RESET_n, // PU on Amiga MB
	inout           M68K_HALT_n, // PU on Amiga MB

// These are dealing with the host original 68k, so their directions are those of a device, not a CPU
	output          M68K_BR_n, // PU on Amiga MB
	input           M68K_BG_n, // No PU on Amiga MB : need PD on expansion in case host original 68k is absent
//	inout           M68K_BGACK_n, // PU on Amiga MB

// EXT
   output          OVR_n,
	output          INT2_n,
	output          INT6_n,
	input           KB_RESET_n,
	output   [10:0] SPARE
 );


  localparam REG_DATA_LO = 3'd0;
  localparam REG_DATA_HI = 3'd1;
  localparam REG_ADDR_LO = 3'd2;
  localparam REG_ADDR_HI = 3'd3;
  localparam REG_STATUS = 3'd4;

  reg pistorm_off = 1'b0; //User has turned off the Pistorm using a long reset
  reg pistorm_alive = 1'b0; //The Pistorm has been detected on the bus since the last manual reset (it is kept active when reset by the Pi)
  wire pistorm_active = pistorm_alive & !pistorm_off;
  reg bus_requested = 1'b0; //When the Pistorm is active, we request is bus to the 68k ; it is relinquished at every system reset, and requested again if Pistorm is still active
  reg bus_granted = 1'b0; //The 68k has granted its bus to the Pistorm

  wire c14m = M68K_CLK;
  
  wire manual_reset; //pulse when reset by the system, not by the Pi
  wire oor; //pulse when out of reset, delayed by one clock pulse (required to prevent lock after reset)

  reg [31:0] data_in;
  reg [31:0] data_out;
  reg [23:0] addr;
  
  reg s2 = 1'd0;
  reg s3 = 1'd0;
  reg s4 = 1'd0;
  reg s7 = 1'd1; //M68K waiting bus state

  reg [2:0] ipl;
  reg [2:0] ipl_a;

  reg bm_out = 1'b0;
  reg reset_out = 1'b0; //1=reset by the Pi, 0=run //was 1 but we must not maintain reset in case pistorm is not alive and to be able to switch using Ctrl+A+A
  reg halt_out = 1'b0;
  reg int2_out = 1'b0;
  reg int6_out = 1'b0;

  reg op_req = 1'b0; //1=operation pending
  reg rw = 1'b1; //1=read, 0=write
//  reg [1:0] op_size = 2'b0; //0=byte, 1=word, 3=longword, (2=3 bytes)
  reg [2:0] fc;

  reg [1:0] size = 2'b0; //0=byte, 1=word, 3=longword, //operation size
  wire [1:0] port_width; // 0=8b, 1=16b, 3=32b //reply from the device ; valid only during s4 !
  wire [1:0] left_shift = addr[1:0] & port_width; // valid only during s4 !
  wire [1:0] transfered = port_width - left_shift; // valid only during s4 !

  wire [7:0] op0_wr=data_out[31:24];
  wire [7:0] op1_wr=data_out[23:16];
  wire [7:0] op2_wr=data_out[15:8];
  wire [7:0] op3_wr=data_out[7:0];
  wire [7:0] op0_rd=M68K_D[31:24];
  wire [7:0] op1_rd=M68K_D[23:16];
  wire [7:0] op2_rd=M68K_D[15:8];
  wire [7:0] op3_rd=M68K_D[7:0];

  assign SPARE[0] = PI_SER_DAT;
  assign SPARE[1] = PI_SER_CLK;


// Pistorm activation, ON/OFF reset timer
//hold Ctrl+A+A during few seconds to toggle pistorm / 68k
  reg [22:0] rst_timer = 23'd0;
//  wire rst_overflow= rst_timer[21]; //3s
  wire rst_pistorm_mode= rst_timer[22]; //6s
//  wire rst_overflow= rst_timer[22] & rst_timer[21] & rst_timer[20]; //10s
  always @(posedge c14m) begin //1 tick is 71ns
    if(M68K_RESET_n)
      rst_timer <= 23'd0;
    else if(!rst_pistorm_mode)
      rst_timer <= rst_timer+1;
  end
  always @(posedge rst_pistorm_mode)
    pistorm_off <= !pistorm_off;
//Pistorm is alive when it has some activity on its bus, until next reset by the user
  wire pistorm_alive_set = (PI_WR ^ PI_RD) & M68K_RESET_n; // if PI_WR and PI_RD are both up, these are the Pi pullups, there is either no emulator started or no SD
  always @(posedge pistorm_alive_set, posedge manual_reset) begin
    if(manual_reset)
      pistorm_alive <= 1'b0;
	 else
      pistorm_alive <= 1'b1;
  end


// BUS ARBITRATION CONTROL
// each time we pull M68K_RESET_n we need to acquire again the bus from the host 68k (need confirmation)
  wire brset = pistorm_active & bm_out & M68K_RESET_n;
  always @(posedge brset, negedge M68K_RESET_n) begin
    if(!M68K_RESET_n)
      bus_requested <= 1'b0;
    else
      bus_requested <= 1'b1;
  end
  wire bgset = bus_requested & M68K_RESET_n & !M68K_BG_n & M68K_AS_n & &M68K_DSACK_n; // & M68K_BGACK_n;
  always @(posedge bgset, negedge M68K_RESET_n) begin
    if(!M68K_RESET_n)
      bus_granted <= 1'b0;
    else
      bus_granted <= 1'b1;
  end


// RESET
// generate the reset signals for our logic, for the host, and for the Pi
  reg [1:0] resetfilter = 2'b11;
  assign oor = resetfilter==2'b01; //pulse when out of reset. delay by one clock pulse is required to prevent lock after reset
  always @(negedge M68K_CLK) begin
    resetfilter <= {resetfilter[0],M68K_RESET_n};
  end
  assign manual_reset = !M68K_RESET_n & !(pistorm_active & reset_out);
//  assign PI_RESET_n = pistorm_off | M68K_RESET_n | reset_out; //Reset the Pi on m68kreset not requested by the pi, only when pistorm is active (otherwise emu68 boot loop)
  assign PI_RESET_n = KB_RESET_n;
  assign M68K_RESET_n = (pistorm_active & reset_out) ? 1'b0 : 1'bz; //Prevent the Pistorm when it is off from resetting the system
  assign M68K_HALT_n = (pistorm_active & halt_out) ? 1'b0 : 1'bz; //To reset both the processor and the external devices, the RESET and HALT input signals must be asserted at the same time


// INTERRUPT CONTROL
  always @(negedge c14m) begin
    ipl_a <= M68K_IPL_n;
    if (ipl_a == M68K_IPL_n) //filter unstable signals
      ipl <= M68K_IPL_n;
  end
//  assign PI_IPL_ZERO = (ipl == 3'd0) & bus_granted;
  assign PI_IPL = ipl & bus_granted;

// PI SIDE
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

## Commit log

2021-07-27 Respository init with KiCAD files, CPLD files, Readme and License
    [PistormX.kicad_pcb, PistormX.sch]
2022-02-08 Kicad : first board revision ; CPLD : working with buptest and emulator, no 200MHz PICLK is used, fixed cold and warm reset
    [PistormX.kicad_pcb, PistormX.sch]
2022-02-13 Kicad: converted to v6, relabeled the Pi signals in schematic, added EXPERIMENTAL and CC-BY-NC-SA on silkscreen ; CPLD: add JED files ; Photo
    [PistormX.kicad_pcb, PistormX.kicad_sch, PistormX.sch]
2022-02-14 Kicad: Gerbers and InteractiveHtmlBom
2022-02-24 Pistorm firmare : added Pistorm'X firmwares for the original Pistorm CPU board
2022-03-01 Pistorm firmare : firmwares for original Pistorm CPU board are now booting in both Musashi and EMU68 but are unstable :(
2023-05-23 New Beta untested boards and firmwares : PiStorm'X 500, PiStorm'X 600 and PiStorm'X 1K2. See README.
    [PistormX1K2.kicad_pcb, PistormX1K2.kicad_sch, PistormX500.kicad_pcb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]
2023-05-25 Added an alternative board layout for the Pistorm'X 1K2. Some cleanup on the first PiStorm'X 1K2 board. Updated README.
    [PistormX1K2.kicad_pcb, PistormX1K2.kicad_sch]
2023-06-03 Pistorm'X DMA debut ; PiStorm'X firmware for the original board with support for Bus Arbitration signals, to hopefully work with DMA peripherals in A2000
2023-10-12 Pistorm'X DMA : renamed the firmware files to indicate the original one they are based on '4 states cycle write buffer' and add the '6 states cycle write buffer' counterpart
2023-10-13 Pistorm'X DMA : added the '8 states cycle' logic for testing purposes
2024-02-22 PiStorm'X 500 and PiStorm'X 600 corrections. PiStorm'X 600 is actually working and under test. PiStorm'X 500 will be tested after I find an Agnus 8375 or A500 motherboard replacement.
    [PistormX500.kicad_pcb, PistormX600.kicad_pcb]
2024-05-08 PiStorm'X 500 DIP : finally working firmware, changed 7MHz clock input pin, adjustments to VMA timing, cleanup. PiStorm'X 600 cleanup. Original PiStorm'X for A500 moved to 'Alpha' folder.
    [PistormX.kicad_pcb, PistormX.kicad_sch]
2024-11-27 PiStorm'X 500 DIP : some adjustments that I hoped would help reduce heat from the CPLD. Not much difference according to my measurements but at least reduces FB inps and Pterms (-27 and -23 respectiv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
2024-12-07 PiStorm'X 500 DIP & PiStorm'X 600: more power adjustments that may reduce heat from the CPLD.
